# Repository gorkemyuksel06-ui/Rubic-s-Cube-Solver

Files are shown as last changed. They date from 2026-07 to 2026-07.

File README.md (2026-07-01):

# Rubik Küp Çözücü Robot

Hacettepe Üniversitesi ELE402 bitirme projesi kapsamında geliştirilen otonom Rubik Küp çözücü robot. Sistem şu anda **Telekom Laboratuvarında** hazır kurulu motor sürücüleriyle birlikte takılı halde bulunmaktadır.

## Sistem Detayları
* **Yazılım & Donanım:** Kodların tamamı **Python** dilinde yazılmıştır ve **Raspberry Pi** üzerinde çalışmaktadır. Çalıştırmak için gereken tüm kodlar bu depoya yüklenmiştir.
* **Algoritma ve Tarama:** Küpün çözümü için **Kociemba algoritması** kullanılmaktadır. Tarama işlemi bu algoritmanın kuralına uygun olarak yapılır (Tarama **Yeşil** merkezli yüzden başlar ve belirlenen sırayla devam eder).
* **Mekanik Durum:** Sistemin 3D dosyaları depoya eklenmiştir. Yazılımsal olarak hiçbir sorun bulunmamaktadır; kodlar ve algoritma sorunsuz çalışmaktadır. Ancak **mekanik anlamda geliştirme yapılması gereklidir.** Projeyi devralacak kişilerin daha stabil bir mekanik tasarım üzerine yoğunlaşması tavsiye edilir.

## Arayüz (UI) İşlevleri
Sistemi kontrol etmek için geliştirilen arayüzün temel özellikleri ve işlevleri şunlardır:
* **Tarama Modülü:** Yeşil yüzden başlayarak Kociemba dizilimine göre küpün renk matrisini kameradan alır ve kaydeder.
* **Çözüm (Algoritma) Motoru:** Taranan güncel renk durumunu işleyerek küpü çözecek minimum hamle dizisini hesaplar.
* **Hareket (Motor) Kontrolü:** Hesaplanmış olan hamle dizisini, Raspberry Pi pinleri üzerinden doğrudan motor sürücülerine aktararak fiziksel çözümü başlatır.
* **Talimatlar ve Durum Paneli:** Tarama sırası, adım takibi ve sistemin o anki durumuyla ilgili kullanıcıya gerekli bilgileri sağlar.

> **Önemli Not:** Arayüz üzerinde sistemi kullanmak için gerekli tüm talimatlar halihazırda bulunmaktadır. Ancak sistemin veya kod bloklarının tam olarak arka planda ne yaptığını daha iyi anlamak isterseniz, ilgili kodları herhangi bir yapay zekaya atarak her şeyi madde madde ve kolayca öğrenebilirsiniz.

## Geliştiriciler
* Görkem Yüksel
* Özge Erdem

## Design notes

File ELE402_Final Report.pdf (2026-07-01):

# ELE 402 - GRADUATION PROJECT II FINAL REPORT

HACETTEPE UNIVERSITY
DEPARTMENT OF ELECTRICAL AND ELECTRONICS ENGINEERING

PROJECT TITLE: Rubik’s Cube Solver

PROJECT GROUP MEMBERS: Özge ERDEM – Görkem YÜKSEL

PROJECT SUPERVISOR: ASSOC. PROF. DR. BARIŞ YÜKSEKKAYA

SUBMISSION DATE: 14.04.2026

SPRING 2025-2026

## ABSTRACT

This final report presents the design, implementation, and testing of the Rubik's Cube Solver, an autonomous robotic system developed within ELE 401 and ELE 402. The system scans a scrambled 3 x 3 x 3 Rubik's Cube using a camera, classifies sticker colors with an HSV-based OpenCV pipeline, computes a solution with the Kociemba two-phase algorithm, and physically executes the moves using six NEMA 17 stepper motors. During ELE 401, the software foundation and solver logic were created; during ELE 402, the project was completed as an integrated Raspberry Pi 4B-based prototype with a custom graphical user interface, a six-motor mechanical frame, and a custom PCB for A4988 motor driver synchronization and power distribution. After the interim report, the final version added the graphical interface, full scan-solve-execute synchronization, and a Random Mix feature that scrambles the cube, clears the stored cube state and previous solution, and forces a new solve operation when the Solve command is pressed. The final design demonstrates an endto-end autonomous solution pipeline and provides a low-cost educational platform for robotics, computer vision, embedded systems, and motion planning.

## CONTENTS

## LIST OF FIGURES AND TABLES

Figure 1. Final electromechanical architecture of the Rubik's Cube Solver | 5
Figure 2. Camera-based color acquisition pipeline | 9
Figure 3. Mechanical system and final six-motor prototype | 10
Figure 4. Preliminary system architecture from the interim design | 12

Figure 5. Custom graphical user interface used for live state display and manual correction
| 13
Figure 6. OpenCV color detection and ROI mapping on the Raspberry Pi | 14

Figure 7. Custom PCB layout and transition from breadboard wiring to centralized motor
control | 16
Figure 8. Final state flowchart with Random Mix and state reset behavior | 18
Figure 9. Standard Rubik's Cube move notation used by the solver and motor parser | 19
Table 1. Main final design requirements and constraints | 5
Table 2. Random Mix feature behavior and validation points | 11
Table 3. Estimated cost analysis of the final prototype | 20

## 1. INTRODUCTION

The Rubik's Cube Solver project aims to build an autonomous robotic system that can solve a standard 3 x 3 x 3 Rubik's Cube without manual intervention after the cube is placed into the mechanism. The final system combines computer vision, embedded control, motor driver electronics, mechanical design, and a graphical user interface. The overall goal is to convert a visually observed scrambled cube into a valid cube-state string, generate a move sequence using the Kociemba two-phase algorithm, and physically rotate the cube faces with six independent stepper motors.

In ELE 401, the project mainly focused on the software concept: the cube-state representation, initial color detection trials, solver integration, and a mobile-applicationoriented workflow. In ELE 402, the project moved from a conceptual and software-only state into an integrated physical prototype. The architecture was redesigned around a Raspberry Pi 4B so that image acquisition, OpenCV processing, solving, GUI control, and motor commands could run locally on a single embedded platform.

The interim report documented two major design iterations: the first iteration established the Raspberry Pi software pipeline with OpenCV and Kociemba, while the second iteration focused on the custom PCB, stepper motor actuation, and 3D-printed mechanical frame. In the final period, the system was further improved with a functional GUI, synchronized scansolve-execute operation, and a Random Mix feature. In this feature, the robot randomly scrambles the cube, intentionally clears the saved cube state and previous solution, and waits for a new Solve command. Therefore, the system does not simply reverse the random sequence; it scans and solves the newly mixed cube again. This final report presents the complete project description, standards, constraints, methods, design iterations, final design, cost analysis, teamwork, and conclusions.

## 2. PROJECT DESCRIPTION

The project is a mechatronic Rubik's Cube solving robot. The user places a cube inside the mechanical frame and starts the operation from the GUI. The camera captures cube-face images, and the software detects the sticker colors using HSV-based segmentation. The detected colors are displayed in the GUI so that the user can manually correct possible detection errors before solving. After a valid cube state is obtained, the Kociemba solver generates a sequence of moves such as U, R', F2, B, L', or D2. The motor-control layer parses these moves and sends step and direction signals to A4988 drivers, which control six NEMA 17 stepper motors, one motor for each cube face.

The final prototype uses a Raspberry Pi 4B as the central controller. It coordinates the camera, OpenCV scripts, GUI, solver, GPIO outputs, motor drivers, and state memory. The custom PCB reduces wiring complexity by centralizing A4988 driver connections, Raspberry Pi GPIO connections, power distribution, and common ground routing. The 3D-printed frame holds the cube in a fixed position and aligns the six motors with the six cube faces. This architecture supports automatic solving, GUI-based manual verification, and the newly added Random Mix command.

Table 1. Main final design requirements and constraints

Requirement / Constraint | Final implementation
Autonomous cube solving | The system performs scan, GUI verification, Kociemba solving, move parsing, and motor execution on the Raspberry Pi.
Six-face actuation | Six NEMA 17 motors are driven through A4988 drivers; one motor is assigned to each cube face.
Solution efficiency | The solver uses the Kociemba two-phase algorithm, targeting solutions under 20 moves for the final demonstration.
Real-time user visibility | The GUI displays the live cube state and allows manual correction before solving.
Random Mix validation | Random Mix scrambles the cube with motor commands, clears stored state, and requires a new solve operation.
Low-cost prototype | The design relies on accessible components: Raspberry Pi, A4988 drivers, NEMA 17 motors, 3D-printed parts, and a custom PCB.

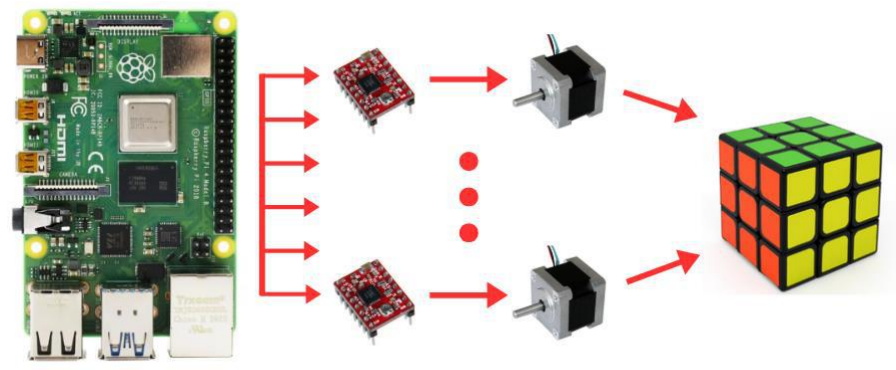
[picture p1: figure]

Figure 1. Final electromechanical architecture of the Rubik's Cube Solver

## 3. ENGINEERING STANDARDS AND DESIGN CONSTRAINTS

## 3.1. ENGINEERING STANDARDS

The final design is a university prototype and is not claimed to be formally certified. However, the design process follows relevant engineering standards and good-practice principles in software, electronics, and mechatronic implementation.

IPC-2221, Generic Standard on Printed Board Design, is relevant to the custom PCB because the board includes motor driver modules, power-distribution paths, connector placement, and signal routing between the Raspberry Pi and six A4988 drivers. In accordance with this design logic, high-current motor paths were separated from low-current GPIO signals as much as possible, connectors were organized to reduce wiring errors, and the PCB was used to improve reliability compared with the breadboard prototype.

IEC 62368-1 safety principles are relevant because the prototype combines a low-voltage computing unit, external motor power, and moving mechanical parts. Although formal product certification was outside the scope of the graduation project, the final design separates logic-level control from motor power, uses a common ground reference, avoids exposed high-voltage circuitry, and keeps the moving cube mechanism inside a fixed frame during operation.

ISO/IEC/IEEE 12207 software life-cycle principles are also applicable at the project level. The final software was divided into color acquisition, GUI verification, solver, random-mix generation, state-memory management, move parsing, and motor-control modules. This modular structure made debugging and final integration easier.

## 3.2. DESIGN CONSTRAINTS

The project was constrained by budget, component availability, time, mechanical precision, lighting conditions, and embedded computation. The robot had to be realizable with parts that could be obtained and assembled within the ELE 402 schedule. The six-motor frame had to fit a standard 3 x 3 x 3 cube while leaving enough clearance for face rotations. The stepper motors had to rotate cube faces by 90 degrees and 180 degrees with sufficiently low angular error. On the software side, the color detection method had to be fast enough to run on the Raspberry Pi and robust enough for the GUI to create a valid cube-state string. The final GUI correction step was therefore included as a practical constraint-management method: a wrong color can be corrected before the solver is run.

## 4. SUSTAINABLE DEVELOPMENT GOALS

The project supports several Sustainable Development Goals at the prototype and educational level. Goal 4, Quality Education, is the strongest match because the robot is a hands-on learning platform for computer vision, embedded systems, motor control, printedcircuit-board design, and mechanical integration. Students can observe how a real mechatronic system moves from algorithmic planning to physical actuation.

Goal 9, Industry, Innovation and Infrastructure, is also supported because the project integrates a custom PCB, a multi-motor actuation structure, and an embedded perceptionand-control pipeline. The architecture is directly related to broader automation tasks such as pick-and-place systems, sorting mechanisms, and low-cost robotic testbeds. Goal 12, Responsible Consumption and Production, is addressed by using 3D-printed replaceable parts and a modular PCB-based architecture, which makes maintenance and component replacement easier than rebuilding the whole system.

## 5. LITERATURE REVIEW

A Rubik's Cube state can be described by the colors or cubie positions of its 54 stickers. Standard cube notation defines face moves U, D, F, B, R, and L, along with prime moves for counter-clockwise rotation and the suffix 2 for 180-degree rotation. This notation is suitable both for solver output and for motor-command parsing because each symbolic move can be mapped directly to one motor, one direction, and one angle.

The selected solving method is the Kociemba two-phase algorithm. Compared with a bruteforce search, Kociemba's approach reduces the solution search space by dividing the problem into phases and using precomputed move tables. This makes it practical to run the solver on an embedded platform such as a Raspberry Pi. The final project therefore uses Kociemba output as the bridge between visual cube-state recognition and physical motor control [1], [2].

For perception, OpenCV is used because it provides efficient image acquisition, color-space conversion, filtering, and region-of-interest operations. HSV color representation was preferred over direct RGB comparison because hue, saturation, and value provide a more intuitive separation of sticker colors under moderate lighting variation. Nevertheless, the interim tests showed that red/orange overlap and reflections can still cause errors, so the final system includes a GUI correction stage before solving [4].

For actuation, stepper motors were selected because they provide discrete angular positioning without requiring a complex feedback controller for a first prototype. A4988 motor driver modules receive step and direction signals from the Raspberry Pi GPIO pins and control the phase currents of the NEMA 17 motors. This structure is simple, widely documented, and suitable for 90-degree and 180-degree cube-face rotations [5], [6].

The literature and project examples on Rubik's Cube solving robots show that successful systems require not only a solver algorithm but also reliable synchronization between scanning, state validation, and mechanical execution. For this reason, the final design emphasizes the full scan-solve-execute loop, GUI verification, and state-reset behavior after random scrambling [7].

## 6. METHODS

## 6.1. CAMERA-BASED COLOR ACQUISITION AND GUI VERIFICATION

The first method is camera-based color acquisition. The camera captures images of cube faces, and each face is divided into nine fixed regions of interest. The mean HSV values of these regions are calculated and classified into the six cube colors: white, yellow, red, orange, blue, and green. The GUI then visualizes the detected state. If one or more stickers are misclassified, the user can manually correct them before the solver is called. This approach was selected because it combines automation with practical robustness: the system remains usable even when lighting conditions are not ideal.

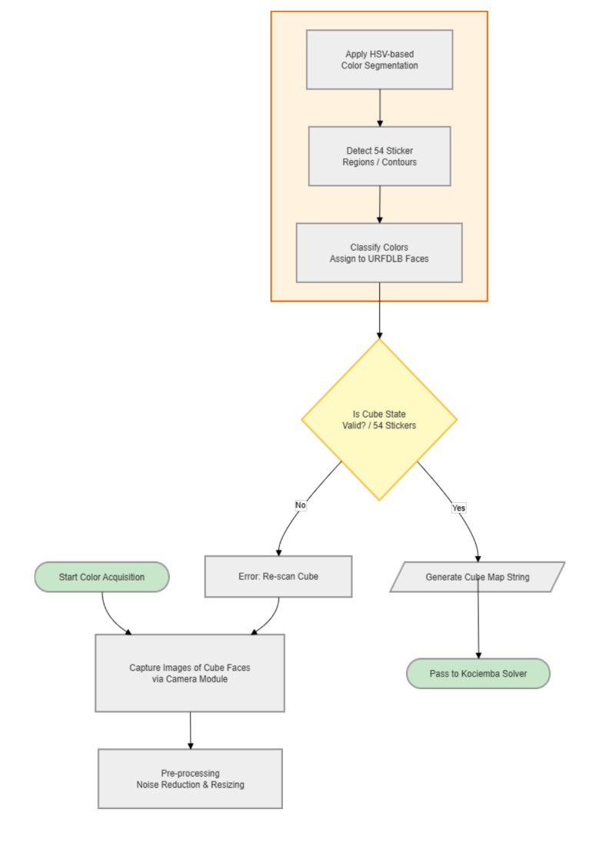
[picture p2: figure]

Figure 2. Camera-based color acquisition pipeline

## 6.2. KOCIEMBA SOLVER AND CUBE STATE ENCODING

The second method is solver-based motion planning. After the GUI confirms that the cube state is valid, the 54 stickers are converted into the face-order required by the solver. The Kociemba module returns a move list in standard notation. The motor parser converts each move into motor index, direction, and number of steps. A move without a suffix corresponds to a 90-degree clockwise rotation; a prime move corresponds to a 90-degree counter-clockwise rotation; a move with the suffix 2 corresponds to a 180-degree rotation.

## 6.3. SIX-MOTOR ACTUATION AND PCB-BASED DRIVER CONTROL

The third method is six-motor face-centered actuation. One NEMA 17 stepper motor is assigned to each cube face. A custom PCB holds or connects the A4988 motor driver modules and distributes power and GPIO signals. The PCB was selected instead of a fully breadboarded system because the final design requires many repeated motor-driver connections. Centralized wiring reduces connection errors and improves demonstration reliability.

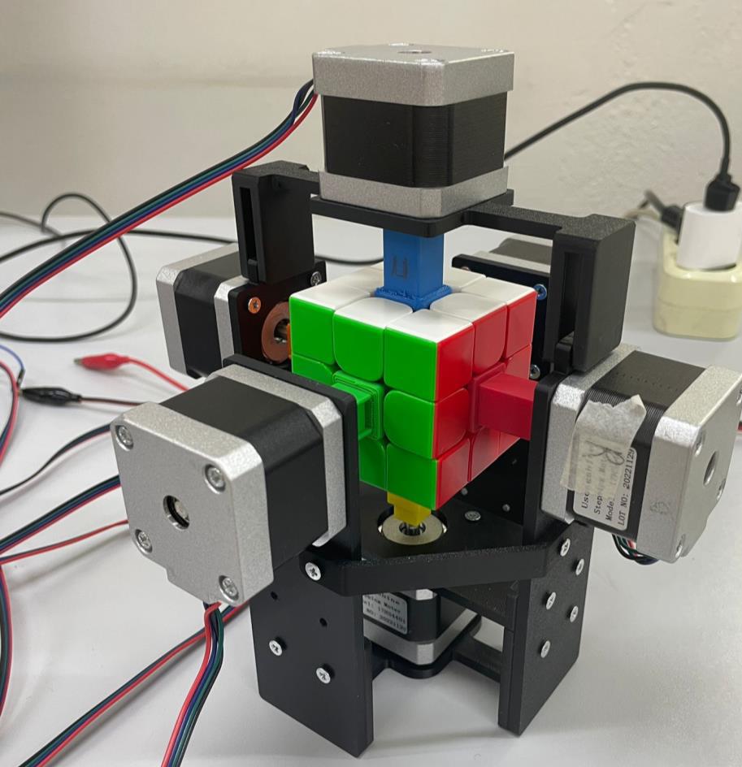
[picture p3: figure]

Figure 3. Mechanical system and final six-motor prototype

## 6.4. RANDOM MIX AND STATE RESET METHOD

The final method added after the interim report is the Random Mix and state reset method. When the user presses Random Mix, the software generates a random legal sequence of cube moves and physically executes this sequence with the motors. After the sequence is executed, the software clears the stored cube-state string and the previous solution list. Therefore, when the user presses Solve, the program cannot simply apply the inverse of the random scramble. It must capture or verify the current cube state again, run the Kociemba solver again, and generate a new solution. This feature validates the autonomy of the complete system.

Table 2. Random Mix feature behavior and validation points

Random Mix step | Purpose in final design
Generate random move sequence | Creates a new physical scramble without requiring the user to hand-mix the cube.
Execute sequence with motors | Verifies that the motor-control layer can perform arbitrary face rotations.
Clear previous state and solution | Prevents the software from solving by reversing a stored scramble sequence.
Wait for Solve command | Forces a new scan/verification/solve operation on the mixed cube.
Run solver again | Demonstrates end-to-end autonomy of the final design.

## 7. PRELIMINARY DESIGN

The preliminary design from ELE 401 was a software-centered structure that combined mobile-app interaction with Python-based solving. The core idea was to obtain the cube colors, send the cube state to a solver, and present the solution to the user. However, this design had two major limitations for the final project: it relied on a separate application pipeline, and it did not yet include a complete physical actuation system.

The preliminary ELE 402 redesign replaced the mobile-oriented workflow with a Raspberry Pibased standalone workflow. The Raspberry Pi was selected as the central controller because it can run Python, OpenCV, the Kociemba solver, a GUI, and GPIO-based motor-control scripts. The preliminary hardware design consisted of a camera module, a six-motor mechanical frame, A4988 drivers, a custom PCB, and a separate motor power supply. The main design parameters were camera position, ROI size, HSV thresholds, cube-face order, motor step count per 90-degree turn, motor speed delay, driver current limit, power distribution, GUI state representation, and emergency stop behavior.

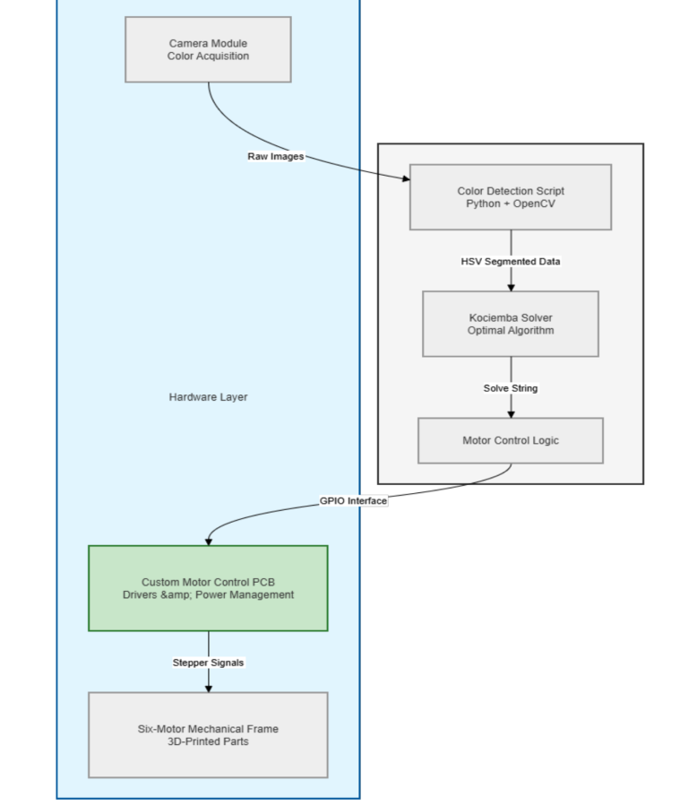
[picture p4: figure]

Figure 4. Preliminary system architecture from the interim design

## 8. PROTOTYPE

The final prototype is a hardware/software integrated Rubik's Cube solving robot. The prototype was built to validate the complete scan-solve-execute sequence in a standalone configuration. Its key features are listed below.

- Raspberry Pi 4B central controller running Python, OpenCV, the GUI, Kociemba solver, random-mix logic, and GPIO motor commands.
- Camera-based color acquisition with HSV segmentation and nine ROIs per cube face.
- Graphical user interface displaying the live cube state and allowing manual color correction before solving.
- Six NEMA 17 stepper motors placed around the cube, one motor per face.
- Six A4988 motor drivers coordinated through Raspberry Pi GPIO pins and a custom PCB.
- 3D-printed frame and cube-face adapters that hold the cube and transfer motor motion to the faces.
- Random Mix feature that scrambles the cube, clears stored state, and requires a fresh solve operation.

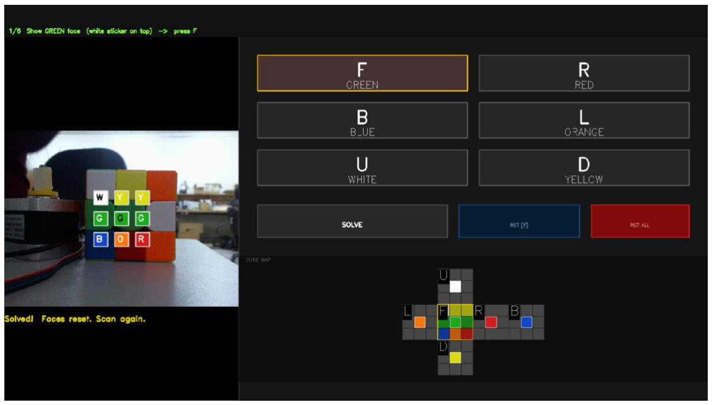
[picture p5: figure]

Figure 5. Custom graphical user interface used for live state display and manual correction

## 9. DESIGN PROCESS AND PROGRESS

The design process was iterative. Each iteration improved a different weakness of the previous version. The first iteration validated the software pipeline, the second iteration added physical motor-control and mechanical implementation, and the third iteration completed the final user workflow with GUI integration, Random Mix, and state-reset logic.

## 9.1. ITERATION 1: SOFTWARE PIPELINE AND COLOR DETECTION

The first iteration focused on developing a self-contained software pipeline on the Raspberry Pi. The camera captured cube-face images, OpenCV converted the images into HSV color space, fixed ROIs isolated the stickers, and the mean HSV values were mapped to six cube colors. The 54 detected stickers were assembled into the solver input string. At this stage, the execution phase remained theoretical and was displayed in the terminal.

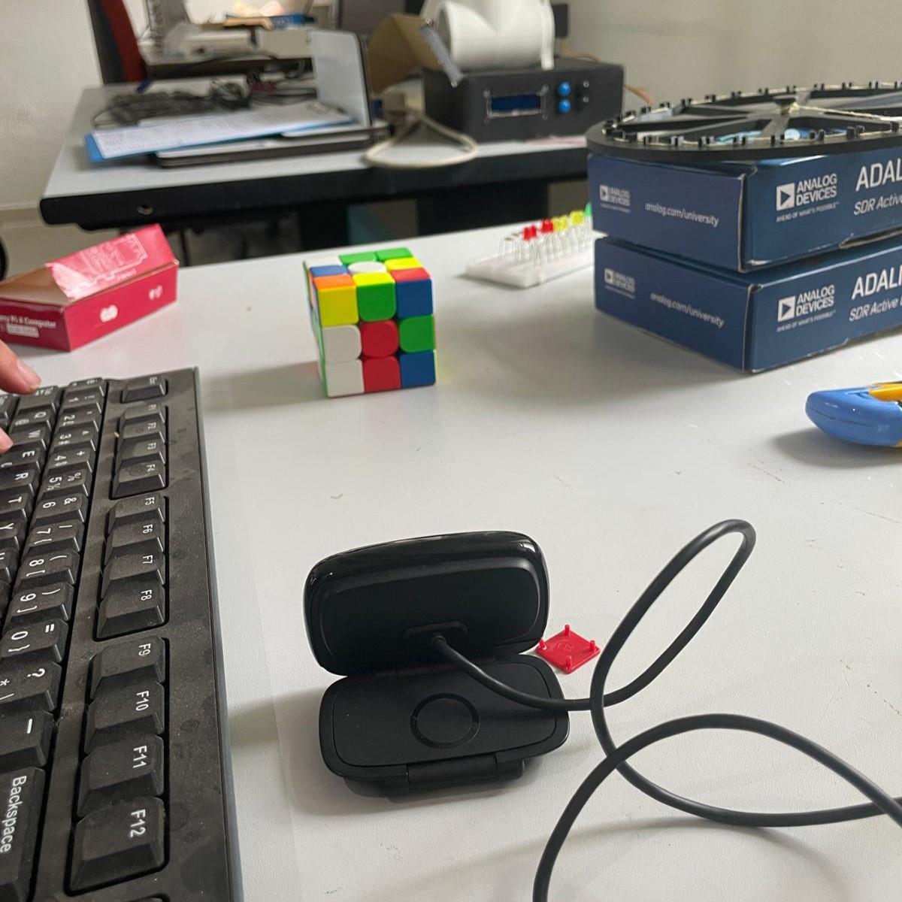
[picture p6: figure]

Figure 6. OpenCV color detection and ROI mapping on the Raspberry Pi

9.1.1. TESTING AND RESULTS
The color-detection module was tested under ambient indoor lighting and direct desk-lamp illumination. In the interim tests, ambient indoor lighting produced approximately 52 correct stickers out of 54 on average, corresponding to about 96 percent accuracy. Under direct desk-lamp illumination, the accuracy decreased to about 89 percent because reflections shifted the apparent hue values. The solver was separately tested with valid cube-state strings and produced valid solutions with an average computation time under 0.8 seconds on the Raspberry Pi.
9.1.2. EVALUATION
This iteration validated the software foundation but revealed two main problems. First, fixed HSV thresholds were sensitive to lighting changes, especially in the red/orange boundary region. Second, the system had no physical actuation, so it could not complete the project goal. The next iteration therefore focused on improved threshold tuning, GUI verification, and hardware integration.

## 9.2. ITERATION 2: MECHANICAL FRAME, PCB, AND MOTOR CONTROL

The second iteration focused on the physical realization of the robot. The mechanical frame was designed and 3D printed. The design uses a face-centered mechanism in which six stepper motors rotate the six cube faces. A custom PCB was designed to host or connect the stepper motor driver modules, organize the GPIO interface, and centralize power distribution. Motor-control scripts were implemented in Python so that each solver move could be translated into a step and direction pulse sequence.

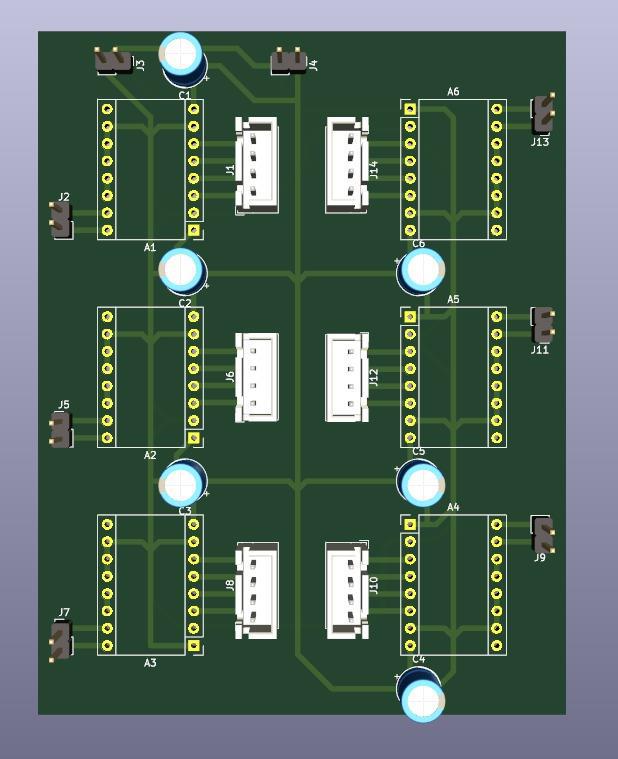
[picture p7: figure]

Figure 7. Custom PCB layout and transition from breadboard wiring to centralized motor control

9.2.1. TESTING AND RESULTS
Before full PCB integration, motor rotation was tested on a breadboard test bench. The interim measurements showed a mean angular error of 1.2 degrees for a 90-degree clockwise turn, 1.5 degrees for a 90-degree counter-clockwise turn, and 2.1 degrees for a 180-degree turn. The 3D-printed parts were also inspected for fit, and the main structural components were found to be suitable for assembly.

9.2.2. EVALUATION
The tests confirmed that the motor-control principle was correct. The remaining weakness was synchronization: the system still needed a final GUI layer, a reliable state transition between scan, solve, and execute, and a method to demonstrate that the robot could solve a cube after it had been automatically mixed by the robot itself. This led to the final iteration.

## 9.3. ITERATION 3: FINAL GUI, RANDOM MIX, AND END-TO-END OPERATION

The third iteration completed the final user workflow. The GUI was integrated with the color-detection, solver, motor-control, and state-memory modules. The user can display the detected cube state, manually correct colors if necessary, solve the cube, execute motor moves, stop the operation, or use the new Random Mix command. Random Mix was added as a final validation feature: the robot first scrambles the cube using a random sequence, then it forgets the stored state and previous solution. When Solve is pressed, the system must solve the current physical cube again.

9.3.1. TESTING AND RESULTS
The final workflow was tested by operating the GUI, executing random motor sequences, clearing the saved state, and running the solve pipeline again. The main observation was that the GUI and state-reset behavior prevented the program from relying on the previous random sequence. This means the solve action remained dependent on the current cube state rather than on a stored inverse scramble. The final poster results reported that the system successfully solves a 3 x 3 x 3 cube using six NEMA 17 stepper motors and a Raspberry Pi 4B, with HSV-based color detection and GUI-supported manual verification.
9.3.2. EVALUATION
The final iteration significantly improved the demonstration value of the project. The Random Mix feature proves that the robot is not only playing back a prepared solution; it can create a new scramble, reset its memory, and solve again from the updated physical configuration. The remaining limitation is that the color detection still depends on lighting stability and user verification. Closed-loop motor feedback and adaptive lighting calibration are recommended for future versions.

## 10. FINAL DESIGN

The final design is a Raspberry Pi 4B-based autonomous Rubik's Cube solving robot. The data path starts from the camera image and ends with physical face rotations. The camera captures cube-face images; OpenCV extracts sticker colors; the GUI displays and validates the state; the Kociemba solver computes the move list; the move parser converts moves into motor commands; the custom PCB and A4988 drivers distribute the control signals; and six NEMA 17 motors rotate the corresponding cube faces.

The final software modules are: image acquisition, HSV segmentation, ROI mapping, GUI display, manual color correction, cube-state validation, Kociemba solving, Random Mix generation, state-memory reset, move parsing, GPIO pulse generation, and stop/error handling. The final hardware modules are: Raspberry Pi 4B, camera, custom PCB, six A4988 drivers, six NEMA 17 motors, power distribution, 3D-printed frame, cube adapters, connectors, and wiring.

The Random Mix command is a central final-design feature. The command generates a random legal move sequence, executes it with the motors, clears the old cube state and solution, and returns the GUI to a ready state. The next Solve command performs a new solve cycle. This design choice makes the demonstration more convincing because the system cannot solve by remembering the random scramble sequence.

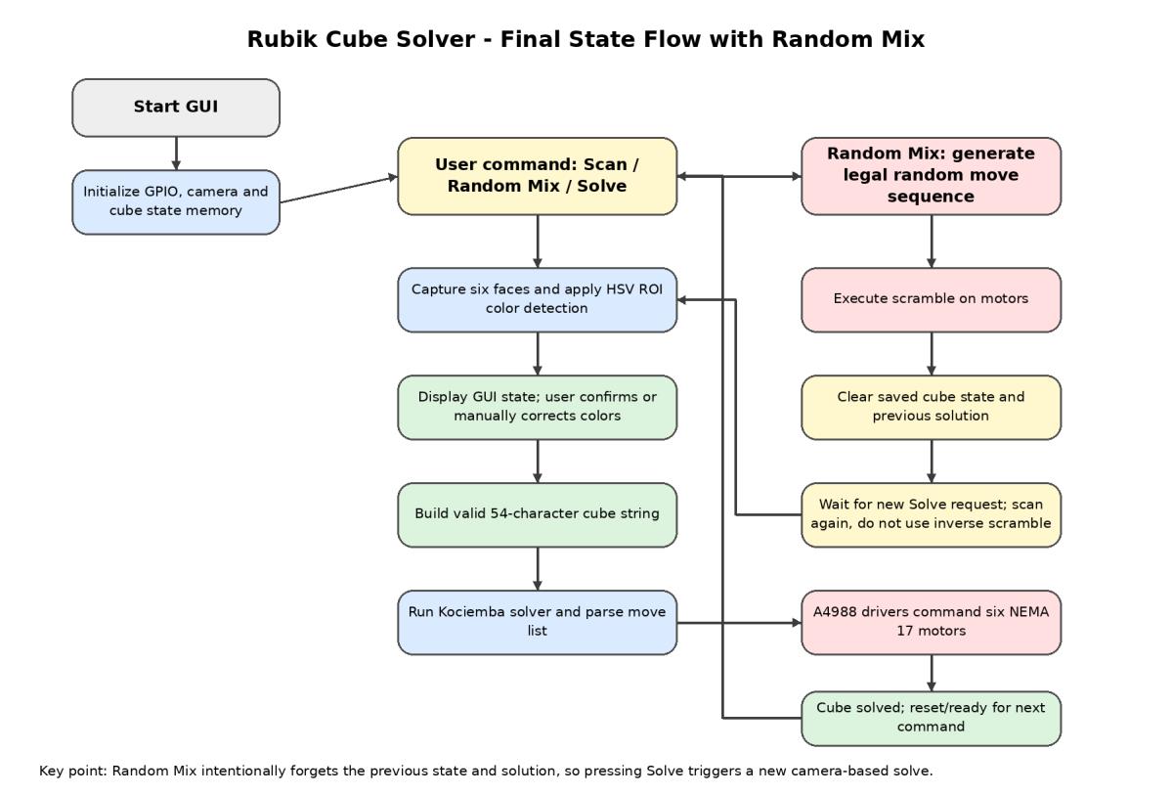
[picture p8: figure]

Figure 8. Final state flowchart with Random Mix and state reset behavior

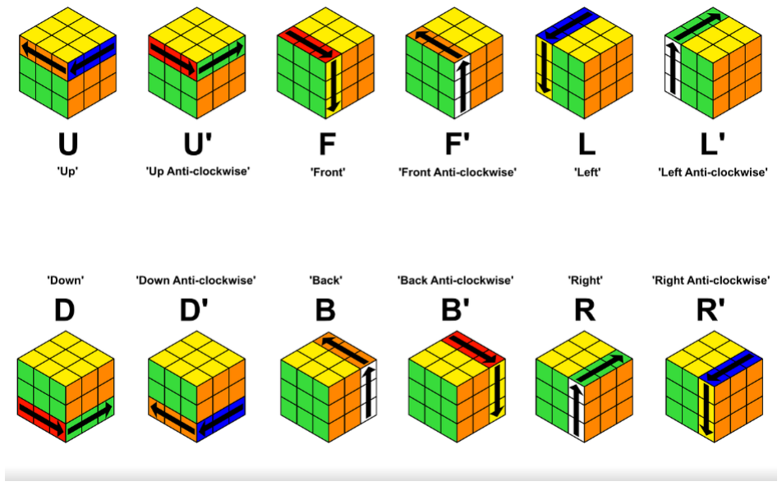
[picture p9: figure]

Figure 9. Standard Rubik's Cube move notation used by the solver and motor parser

The final design meets the core project objectives. It integrates computer vision, motion planning, embedded control, motor driver electronics, and a mechanical frame. Its strongest features are modularity, low-cost implementation, and the GUI-supported correction workflow. Its main weaknesses are sensitivity to lighting conditions, open-loop stepper operation, and the need for careful mechanical alignment. These weaknesses are acceptable for a graduation-project prototype and provide clear directions for future improvement.

## 10.1. MEETING THE CONSTRAINTS AND ENGINEERING STANDARDS

The final design meets the functional constraint of scan-solve-execute operation by using the Raspberry Pi as a single coordination unit. It meets the mechanical constraint through a six-motor frame that allows each cube face to be rotated independently. It meets the cost constraint by relying on affordable and accessible components rather than industrial robot hardware. The PCB improves reliability and follows the PCB-design intent of IPC-2221 by replacing unstable breadboard wiring with organized routing and connectors. Low-voltage safety principles were addressed by separating logic and motor power, limiting the prototype to low-voltage operation, securing the cube in a frame, and avoiding user contact with moving parts during operation.

The software was organized into modules in line with software life-cycle good practice. Color acquisition, GUI verification, solver logic, random mixing, state reset, and motor-control functions can be tested separately. The final Random Mix behavior also satisfies a validation constraint: solving must be based on the actual cube state after scrambling rather than on a stored solution.

## 10.2. COST ANALYSIS

The cost analysis below gives estimated prototype costs. Actual prices may vary depending on supplier, exchange rate, and previously available lab materials.

Table 3. Estimated cost analysis of the final prototype

Component | Quantity | Estimated unit cost (USD) | Estimated subtotal (USD)
Raspberry Pi 4B | 1 | 85 | 85
Camera / webcam module | 1 | 15 | 15
NEMA 17 stepper motor | 6 | 12 | 72
A4988 stepper motor driver | 6 | 3 | 18
Custom PCB manufacturing | 1 | 25 | 25
12 V motor power supply | 1 | 20 | 20
3D-printed PLA frame and adapters | 1 set | 30 | 30
Connectors, wiring, screws, couplers | 1 set | 30 | 30
Rubik's Cube | 1 | 8 | 8
Total estimated cost | | | 303

The estimated total cost is approximately 303 USD. Considering that the prototype includes computer vision, a graphical interface, six independent motors, motor drivers, a custom PCB, and a mechanical frame, the cost is reasonable for an educational mechatronics platform.

## 11. TEAMWORK

The project was completed by Özge Erdem and Görkem Yüksel. Both members contributed to the overall system design, debugging, testing, and final demonstration. The individual contributions are summarized below.

- Özge Erdem (2210357057): Worked on the computer-vision pipeline, HSV color calibration, GUI workflow, manual correction logic, Random Mix state-reset behavior, system testing, report preparation, and final documentation.
- Görkem Yüksel (2210357094): Worked on mechanical design, 3D-printed frame preparation, PCB design and motor-driver organization, stepper motor control tests, system integration, poster preparation, and final demonstration support.
- Joint work: Kociemba solver integration, cube-state validation, move parser debugging, end-to-end testing, final result evaluation, and preparation of presentation materials.

## 12. COMMENTS AND CONCLUSIONS

This report presented the final status of the Rubik's Cube Solver graduation project. The project started as a software-oriented solver concept and was completed as a functional mechatronic prototype. The final design uses a Raspberry Pi 4B, camera-based HSV color detection, Kociemba solving, GUI-based manual verification, a custom PCB, six A4988 motor drivers, six NEMA 17 stepper motors, and a 3D-printed mechanical frame. The design achieved the main objective of building an autonomous system that can scan, solve, and physically manipulate a standard 3 x 3 x 3 Rubik's Cube.

The most important final improvement was the Random Mix feature. With this feature, the robot can scramble the cube by itself, clear the stored cube state and previous solution, and then solve the cube again when the Solve command is pressed. This addition strengthens the demonstration because it verifies that the system relies on the current physical cube state rather than a memorized inverse scramble.

The final design is successful as a low-cost educational prototype. It demonstrates the integration of computer vision, embedded programming, motor control, PCB design, and mechanical prototyping. The remaining limitations are mostly related to lighting sensitivity, open-loop motor control, and mechanical tolerance. Future work should focus on adaptive lighting compensation, automatic camera calibration, closed-loop face-position feedback using encoders or limit sensors, improved acceleration/deceleration profiles, and a more rigid enclosure for repeatable alignment.

## REFERENCES

[1] H. Kociemba, "Two-phase algorithm for solving Rubik's Cube," Cube Explorer Documentation, 1997. Available: https://kociemba.org/cube.htm
[2] H. Kociemba, "hkociemba/RubiksCube-TwophaseSolver," GitHub, Jan. 08, 2021. Available: https://github.com/hkociemba/RubiksCube-TwophaseSolver
[3] D. Singmaster, Notes on Rubik's Cube. Enslow Publishers, 1981.
[4] G. Bradski, "The OpenCV Library," Dr. Dobb's Journal of Software Tools, 2000.
[5] Raspberry Pi Foundation, "Raspberry Pi Documentation - Hardware and GPIO," 2024. Available: https://www.raspberrypi.com/documentation/
[6] Allegro MicroSystems, "A4988 DMOS Microstepping Driver with Translator and Overcurrent Protection," Datasheet.
[7] C. T. Huang et al., "Design and control of a Rubik's Cube solving robot," IEEE Transactions on Automation Science and Engineering, vol. 14, no. 3, pp. 1385-1395, Jul. 2017.
[8] IPC, IPC-2221: Generic Standard on Printed Board Design.
[9] IEC, IEC 62368-1: Audio/video, information and communication technology equipment -Safety requirements.
[10] ISO/IEC/IEEE, ISO/IEC/IEEE 12207: Systems and software engineering - Software life cycle processes.
[11] Autodesk, "Tinkercad - 3D Design and Electronics Modeling," 2024. Available: https://www.tinkercad.com/
[12] Bambu Lab, "MakerWorld - 3D Model Community and Printing Resources," 2024. Available: https://makerworld.com/

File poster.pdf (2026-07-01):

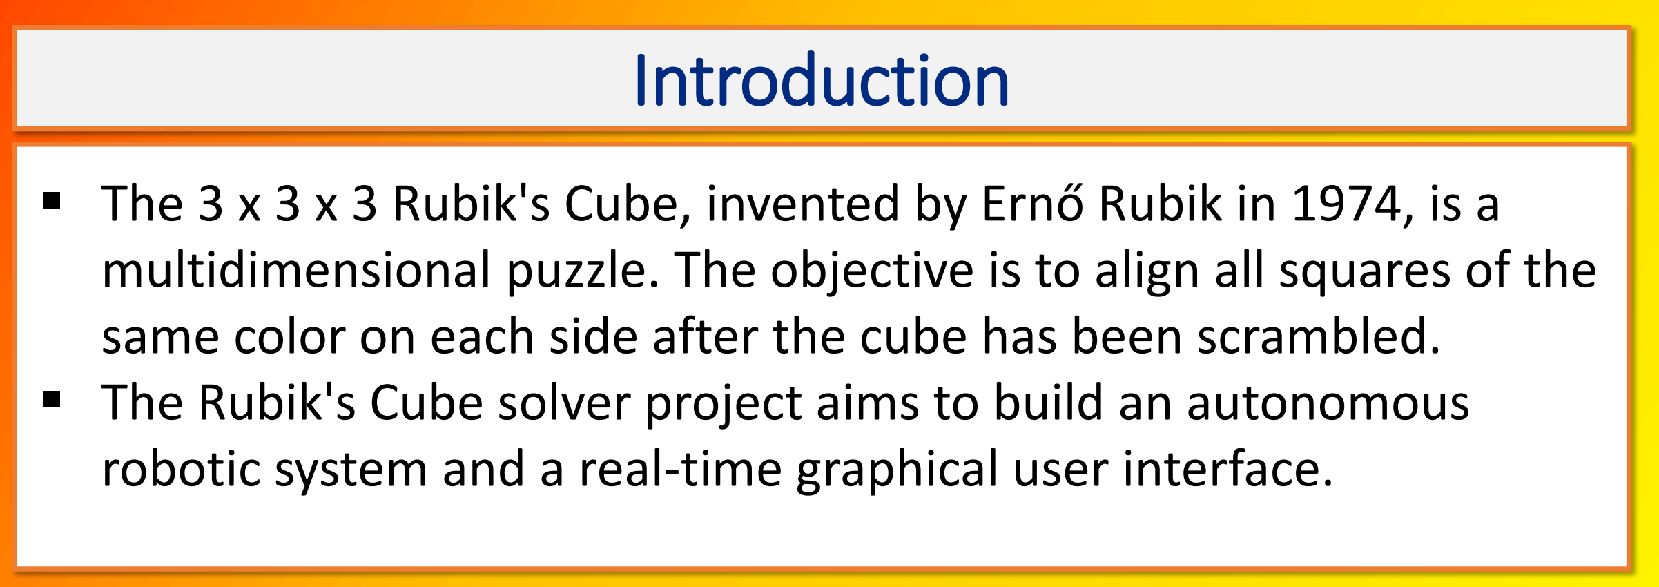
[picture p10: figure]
Introduction

- The 3 x 3 x 3 Rubik's Cube, invented by Ernő Rubik in 1974, is a multidimensional puzzle. The objective is to align all squares of the same color on each side after the cube has been scrambled.
- The Rubik's Cube solver project aims to build an autonomous robotic system and a real-time graphical user interface.

## Supervisor

### Associate Professor Dr. Barış Yüksekkaya

Electrical and Electronics Engineering, Hacettepe University

## Görkem Yüksel, Özge Erdem

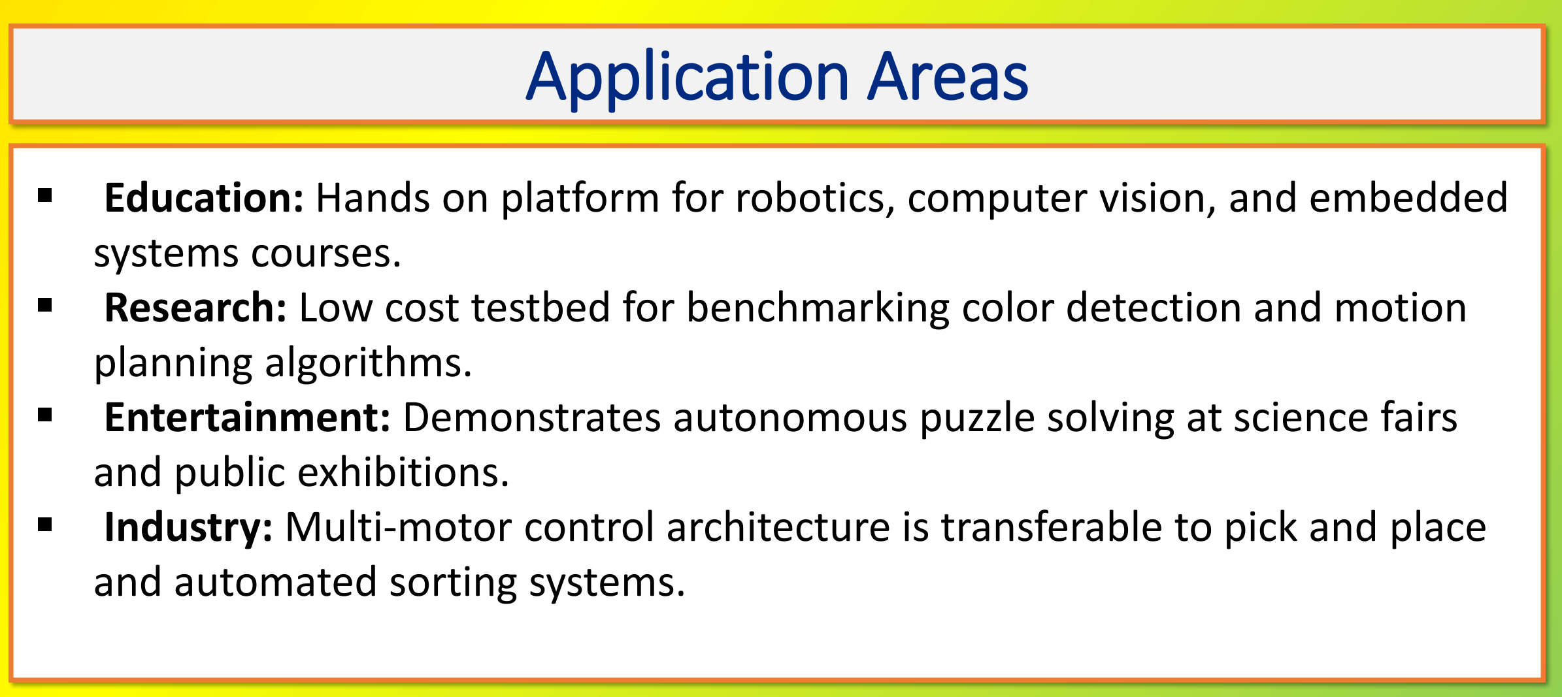
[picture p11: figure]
systems courses.; planning algorithms.; and public exhibitions.; and automated sorting systems.; Application Areas

- Education: Hands on platform for robotics, computer vision, and embedded
- Research: Low cost testbed for benchmarking color detection and motion
- Entertainment: Demonstrates autonomous puzzle solving at science fairs
- Industry: Multi-motor control architecture is transferable to pick and place

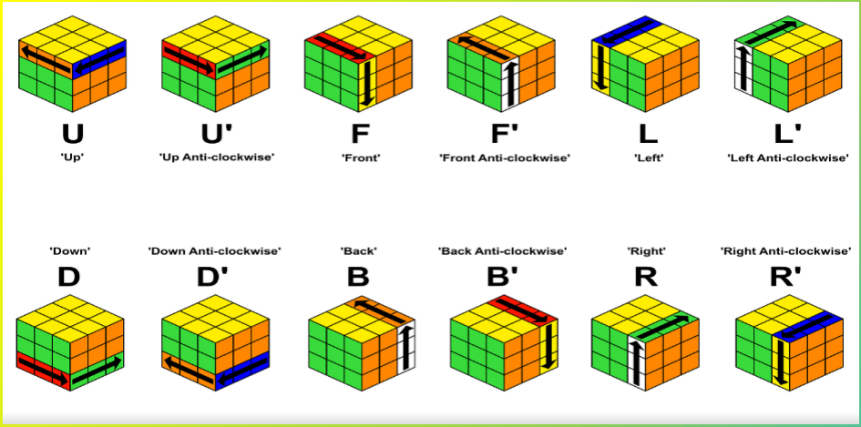
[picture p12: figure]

- Robotic System: A system consisting of 6 independent NEMA 17 stepper motors is built to solve a 3 x 3 x 3 Rubik's Cube
- Performance: The objective is to achieve a solution in less than 20 moves using Kociemba's algorithm.
- Electronics: A custom PCB is utilized to manage motor driver synchronization and power distribution.
- User Interface: A real-time graphical interface is developed to display the live cube state and provide manual correction tools.

## Specifications and Design Requirements

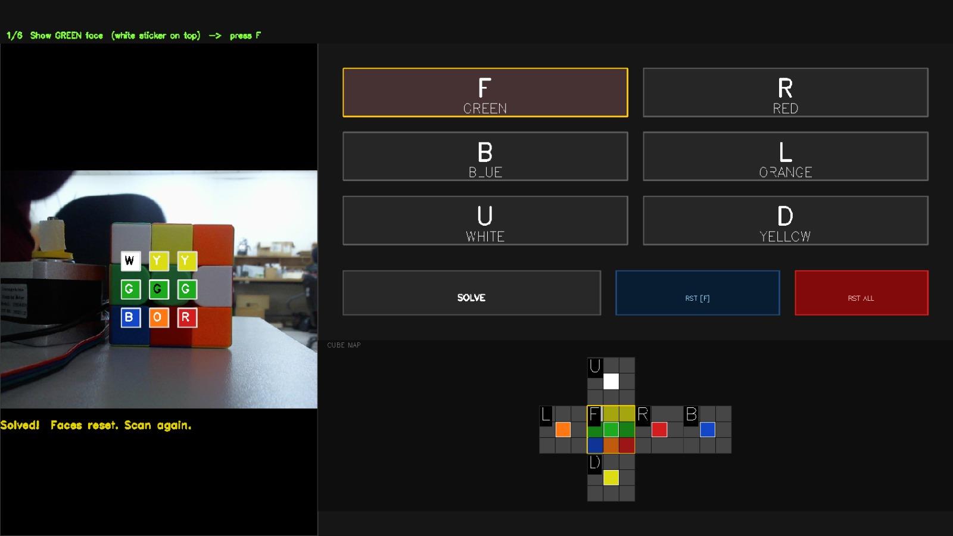
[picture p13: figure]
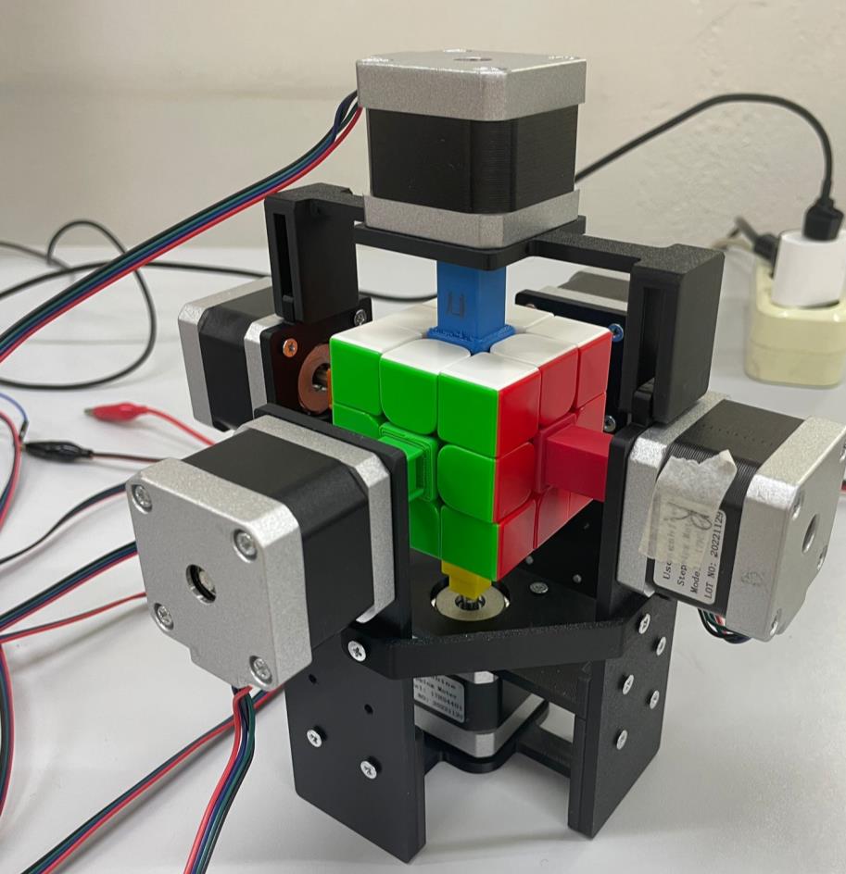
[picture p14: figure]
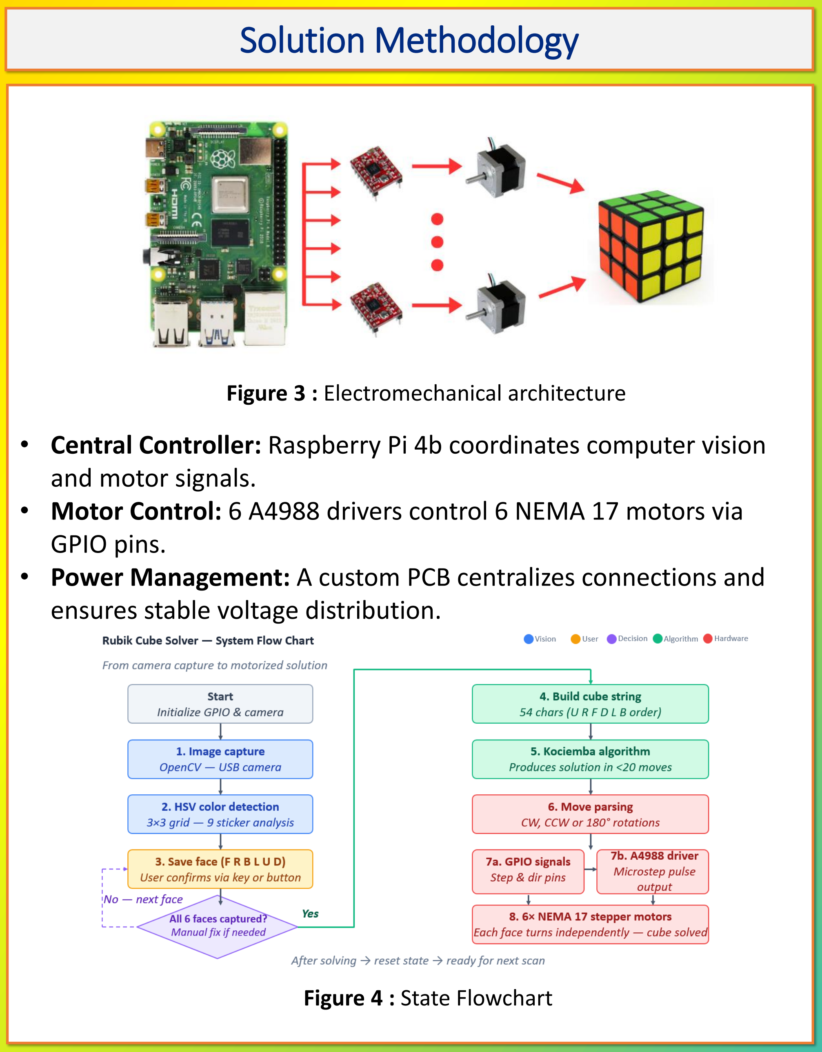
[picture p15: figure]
and motor signals.; GPIO pins.; ensures stable voltage distribution.; Solution Methodology; Figure 4 : State Flowchart

- Central Controller: Raspberry Pi 4b coordinates computer vision
- Motor Control: 6 A4988 drivers control 6 NEMA 17 motors via
- Power Management: A custom PCB centralizes connections and
- Kociemba, H. "hkociemba/RubiksCube-TwophaseSolver," GitHub, Jan. 08,
2021. | https://github.com/hkociemba/RubiksCube-TwophaseSolver
(accessed Nov. 10, 2024).
- Raspberry Pi Foundation, "Raspberry Pi Documentation - Hardware and GPIO," 2024. https://www.raspberrypi.com/documentation/
- "Using Python OpenCV to Detect Squared Regions for Rubik's Cube Scanning,"StackOverflow,2021. https://stackoverflow.com/questions/68559863/using-python-opencv-toaccurately (https://stackoverflow.com/questions/68559863/using-python-opencv-to-accurately-find-squares-from-processed-image-for-rubiks)- (https://stackoverflow.com/questions/68559863/using-python-opencv-to-accurately-find-squares-from-processed-image-for-rubiks)find (https://stackoverflow.com/questions/68559863/using-python-opencv-to-accurately-find-squares-from-processed-image-for-rubiks)- (https://stackoverflow.com/questions/68559863/using-python-opencv-to-accurately-find-squares-from-processed-image-for-rubiks)squares (https://stackoverflow.com/questions/68559863/using-python-opencv-to-accurately-find-squares-from-processed-image-for-rubiks)- (https://stackoverflow.com/questions/68559863/using-python-opencv-to-accurately-find-squares-from-processed-image-for-rubiks)from (https://stackoverflow.com/questions/68559863/using-python-opencv-to-accurately-find-squares-from-processed-image-for-rubiks)- (https://stackoverflow.com/questions/68559863/using-python-opencv-to-accurately-find-squares-from-processed-image-for-rubiks)processed (https://stackoverflow.com/questions/68559863/using-python-opencv-to-accurately-find-squares-from-processed-image-for-rubiks)- (https://stackoverflow.com/questions/68559863/using-python-opencv-to-accurately-find-squares-from-processed-image-for-rubiks)image (https://stackoverflow.com/questions/68559863/using-python-opencv-to-accurately-find-squares-from-processed-image-for-rubiks)- (https://stackoverflow.com/questions/68559863/using-python-opencv-to-accurately-find-squares-from-processed-image-for-rubiks)for (https://stackoverflow.com/questions/68559863/using-python-opencv-to-accurately-find-squares-from-processed-image-for-rubiks)- (https://stackoverflow.com/questions/68559863/using-python-opencv-to-accurately-find-squares-from-processed-image-for-rubiks)rubiks (https://stackoverflow.com/questions/68559863/using-python-opencv-to-accurately-find-squares-from-processed-image-for-rubiks)

## References

- This project was completed within the context of ELE401-402 Graduation Project courses in Hacettepe University, Faculty of Engineering, Department of Electrical and Electronics Engineering.
- We thank Associate Professor Dr. Barış Yüksekkaya for his invaluable contributions to our project.

## Acknowledgements

- Results: The system successfully solves a 3 x 3 x 3 Rubik's Cube autonomously using 6 NEMA 17 stepper motors and a Raspberry Pi 4B. HSVbased color detection identifies all 6 face colors via webcam, supported by a custom GUI for manual verification.
- Performance: The system achieves a high-speed solve, Kociemba's algorithm generates optimal solutions (under 20 moves) in.
- Specifications Achieved: 6-motor high-speed synchronized control via a custom PCB, real-time OpenCV color detection, and a functional graphical interface were successfully implemented.
- Implications: The integration of high speed actuation and real-time computer vision demonstrates an advanced level of system coordination and motion planning.
- Future Work: Adaptive lighting compensation and closed loop feedback could further increase color detection robustness and rotation precision.

## Results and Discussion

Figure 1: Mechanical System Figure 2: Custom Graphical User Interface (GUI)

Figure 3 : Electromechanical architecture

Figure 5: Standard Rubik's Cube move notation

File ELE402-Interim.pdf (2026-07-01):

# ELE 402 - GRADUATION PROJECT II INTERM REPORT

HACETTEPE UNIVERSITY
DEPARTMENT OF ELECTRICAL AND ELECTRONICS ENGINEERING

### PROJECT TITLE: Rubik’s Cube Solver

### PROJECT GROUP MEMBERS: Özge ERDEM – Görkem YÜKSEL

PROJECT SUPERVISOR: ASSOC. PROF. DR. BARIŞ YÜKSEKKAYA

SUBMISSION DATE: 26.04.2026

### SPRING 2025-2026

## TABLE OF CONTENTS

## CONTENTS

TABLE OF CONTENTS | 1
LIST OF FIGURES AND TABLES | 1

### 1. INTRODUCTION | 1

### 2. PROTOTYPE | 2

### 3. DESIGN PROCESS & PROGRESS | 5

### 3.1. ITERATION 1 : SOFTWARE PIPELINE & COLOR DETECTION | 5

### 3.1.1. TESTING AND RESULTS | 7

### 3.1.2. EVALUATION | 7

### 3.2. ITERATION 2 (YOU MAY REPLACE WITH THE NAME OF THE PROCESS) | 8

### 3.2.1. TESTING AND RESULTS | 10

### 3.2.2. EVALUATION | 11

REFERENCES | 13

## LIST OF FIGURES AND TABLES

Figure 1- Overall system architecture of the Rubik’s Cube Solver Robot | 3
Figure 2 - Raspberry pi camera-Based color acquısıtıon pıpelıne | 4
Figure 3 - Real-time OpenCV color detection and region-of-interest (ROI) mapping running on the
Raspberry Pi | 6
Figure 4 - CAD rendering of the mechanıcal frame | 8
Figure 5 - 3D printed mechanical frame components before assembly | 9
Figure 6 - 3D printed central support | 9
Figure 7 - Custom PCB layout desıgn for stepper motors | 10
Figure 8- Design process flowchart | 12

## 1. INTRODUCTION

This report presents the interim progress of the ELE 402 Graduation Project II, a

continuation of the Rubik’s Cube Solver Robot developed in ELE 401. The project aims

to design and build a fully automated system capable of scanning a scrambled Rubik’s

Cube, computing an optimal solution using the Kociemba two-phase algorithm, and

executing the physical moves via a six-motor robotic mechanism.

In the previous semester (ELE 401), the software foundation was established: the

mobile application prototype was created using Flutter, the Kociemba solver was

successfully integrated, and initial color detection experiments were performed. The

physical robot, however, remained at a conceptual design stage.

This semester, the project transitioned into the physical implementation phase. The

primary architectural change from the previous semester is the replacement of the

Flutter+Python mobile pipeline with a Raspberry Pi-based standalone system, where a

camera module handles image acquisition, Python processes color information using

OpenCV, and the Kociemba solver runs locally on the Raspberry Pi. This simplifies the

communication stack and improves system reliability. In addition, the 3D-printed

mechanical parts for the six-motor face-centered rotation mechanism have been

fabricated, and a custom PCB for stepper motor control has been designed and sent to

manufacturing. This report describes the prototype built so far and discusses the two main

design iterations carried out to reach the current state.

## 2. PROTOTYPE

The current prototype of the Rubik’s Cube Solver Robot is a hardware/software integrated

system composed of four main subsystems:

- Raspberry Pi Control Unit: A Raspberry Pi serves as the central processing unit. It runs the color detection script (Python + OpenCV), executes the Kociemba solver, and will issue motor control commands once the mechanical assembly is complete.
- Camera-Based Color Acquisition: A camera module mounted on the Raspberry Pi captures images of each face of the Rubik’s Cube. HSV-based color segmentation is applied to detect and classify the 54 sticker colors.
- Six-Motor Mechanical Frame: The six-motor face-centered rotation mechanism uses one stepper motor per cube face. All 3D-printed structural parts have been fabricated. Assembly is pending integration with the PCB.
- Custom Motor Control PCB: A dedicated PCB has been designed to drive the six stepper motors. The board integrates motor drivers, power management circuitry, and GPIO interfaces for the Raspberry Pi. The board has been submitted for manufacturing.

The purpose of the prototype is to validate the full “scan → solve → execute” pipeline in

an integrated, standalone configuration without reliance on a separate mobile application.

At the current stage, the software pipeline (color detection and solver) is functional on

the Raspberry Pi, the mechanical parts are ready for assembly, and motor rotation logic

has been verified on a test bench.

A placeholder for the system overview figure is provided below. A photograph of the

current physical prototype should be inserted here once the mechanical assembly is

completed.

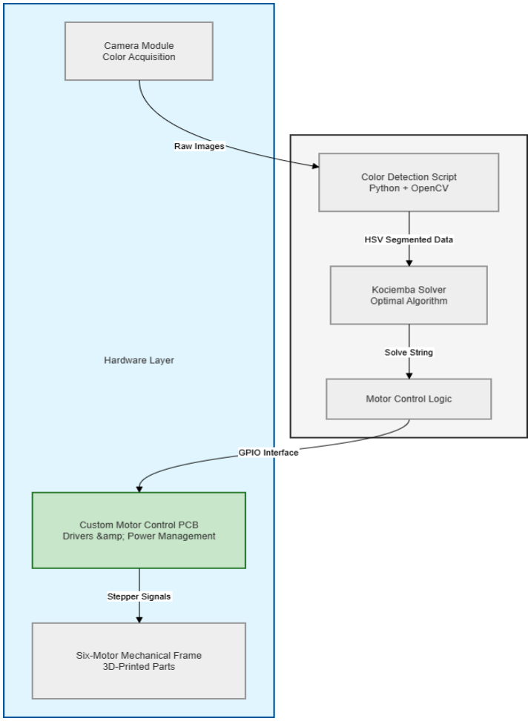
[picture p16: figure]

FIGURE 1- OVERALL SYSTEM ARCHITECTURE OF THE RUBIK’S CUBE SOLVER ROBOT

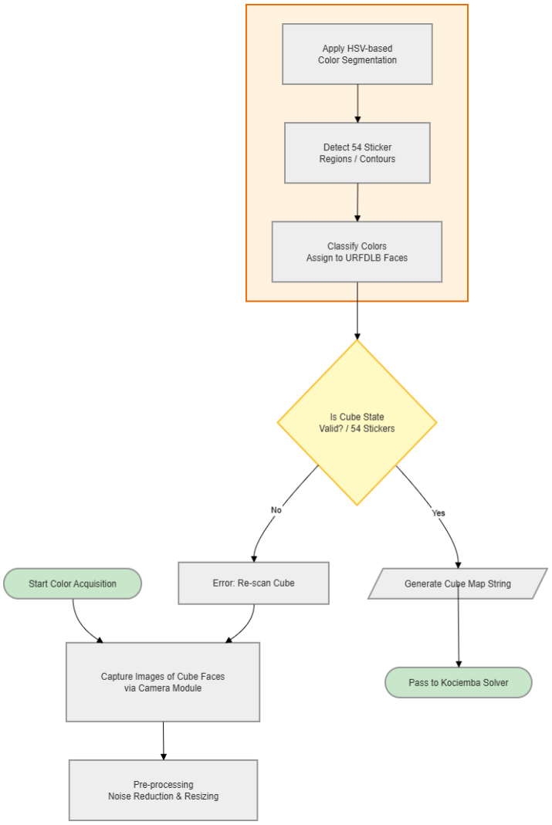
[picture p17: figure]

FIGURE 2 - RASPBERRY PI CAMERA-BASED COLOR ACQUISITION PIPELINE

## 3. DESIGN PROCESS & PROGRESS

The engineering design process for the Rubik’s Cube Solver Robot was carried out in Two main iterations, focusing on the transition from a software-only simulation to a physical hardware prototype.

- First Iteration: This phase was dedicated to developing the core logic on the Raspberry Pi. The primary goal was to establish a functional software pipeline involving OpenCV for color detection and the Kociemba algorithm for solving. At this stage, the system did not include any motor control hardware or physical components. Although the solver worked in a terminal environment, the color detection module suffered from high error rates under varying light conditions, and the "execute" phase of the project remained entirely theoretical.
- Second Iteration: The second iteration focused on the physical implementation and hardware-software integration. A custom motor control PCB was designed and manufactured to interface the Raspberry Pi with six stepper motors. We addressed the previous errors by refining the HSV color segmentation thresholds for improved stability. On the hardware side, all components of the mechanical frame were successfully 3D-printed. While the final assembly of the frame is still in progress, the motor control logic was successfully verified by testing the individual stepper motors. This iteration successfully synchronized the "scan" and "solve" steps with the preliminary "execute" commands, resolving the main synchronization issues from the first phase.

### 3.1. ITERATION 1 : SOFTWARE PIPELINE & COLOR DETECTION

The primary goal of the first design iteration was to establish a functional, selfcontained software pipeline on the Raspberry Pi. This involved achieving reliable color classification for the Rubik’s Cube faces and verifying the Kociemba solving algorithm, operating entirely independent of any physical motor mechanisms or mechanical frame.

The pipeline operates as follows: the Raspberry Pi camera captures an image of each face of the cube. The image is converted from the RGB color space to HSV, and a fixed region-of-interest (ROI) grid is applied to isolate each of the nine sticker regions. The average HSV value within each ROI is computed, and a classifier maps each average value to one of the six cube colors (white, yellow, red, orange, blue, green). The 54 classified colors are assembled into the 54-character state string required by the Kociemba solver. Once a valid state string is obtained, the solver runs locally on the Raspberry Pi and outputs the solution in standard cube notation. At this stage, the execution phase remained theoretical in the terminal environment.

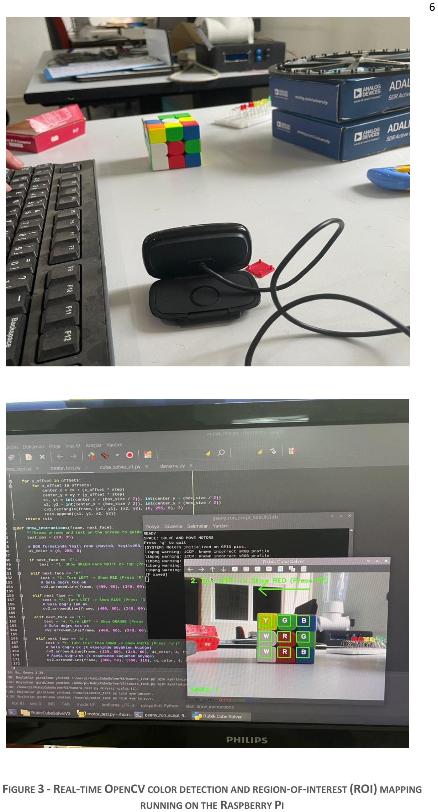
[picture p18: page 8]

FIGURE 3 - REAL-TIME OPENCV COLOR DETECTION AND REGION-OF-INTEREST (ROI) MAPPING RUNNING ON THE RASPBERRY PI

### 3.1.1. TESTING AND RESULTS

The software requirements were tested in two separate modules: color detection accuracy and solver efficiency.

The color detection module was tested by scanning three different scrambled cubes under two lighting conditions: ambient indoor lighting and direct desk lamp illumination. For each configuration, the detected color string was compared against the known ground-truth state.

- Ambient Indoor Lighting: The pipeline achieved correct classification for 52 out of 54 stickers on average, corresponding to an accuracy of approximately 96%. The two misclassified stickers were consistently in the orange/red boundary region, where the HSV hue ranges overlap.
- Direct Desk Lamp Illumination: The accuracy dropped to approximately 89% due to specular reflections on the sticker surfaces, which shifted the apparent hue values.

The Kociemba solver was tested separately with 20 valid, programmatically generated cubestate strings. In all 20 cases, the solver produced a valid solution sequence with an average length of 21 moves and an average computation time of under 0.8 seconds on the Raspberry Pi.

Overall, while the solver performance satisfactorily met the requirements, the color detection robustness under varying lighting conditions was not satisfactorily satisfied.

### 3.1.2. EVALUATION

This initial iteration successfully validated the core logic of the project. The primary strength of the design is the efficiency of the standalone Python implementation on the Raspberry Pi; the Kociemba solver operates rapidly and requires no further optimization.

However, the design exhibited notable weaknesses that must be addressed:

1. Lighting Sensitivity: The use of fixed HSV threshold ranges proved inadequate for changing illumination. The orange/red misclassification is a critical point of failure, as a single wrong color renders the state string invalid.
2. Lack of Physical Actuation: Without hardware integration, the system cannot physically execute the calculated moves, leaving the project incomplete.

To improve the design in the next iteration, the following modifications are necessary:

- Software Enhancement: Refine the HSV color segmentation thresholds or introduce an adaptive calibration step (e.g., sampling the white center sticker first to baseline the lighting) to fix the orange/red overlap.
- Hardware Integration: Transition from a software-only simulation to a physical prototype. This requires designing and manufacturing a custom motor control PCB to interface with the Raspberry Pi, printing the 3D mechanical frame components, and verifying individual stepper motor operations to complete the "scan → solve → execute" pipeline.

### 3.2.ITERATION 2 (YOU MAY REPLACE WITH THE NAME OF THE PROCESS)

The second design iteration focused on the physical realization of the robot. The objectives were: (1) to fabricate the 3D-printed structural components of the six-motor face-centered frame, (2) to design a custom PCB for stepper motor control, and (3) to verify that the motor rotation logic produces correct 90° and 180° face turns.

The mechanical design was finalized in CAD software. The frame consists of six motor mounts, one per cube face, connected by a central support structure that holds the cube in a fixed position during rotation. Stepper motors were chosen for precise angular positioning. The structural components were successfully printed in PLA using the Bambu Lab P1S.

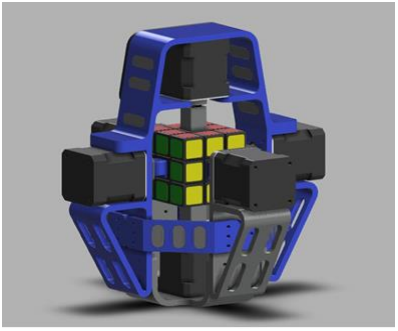
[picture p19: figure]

FIGURE 4 - CAD RENDERING OF THE MECHANICAL FRAME

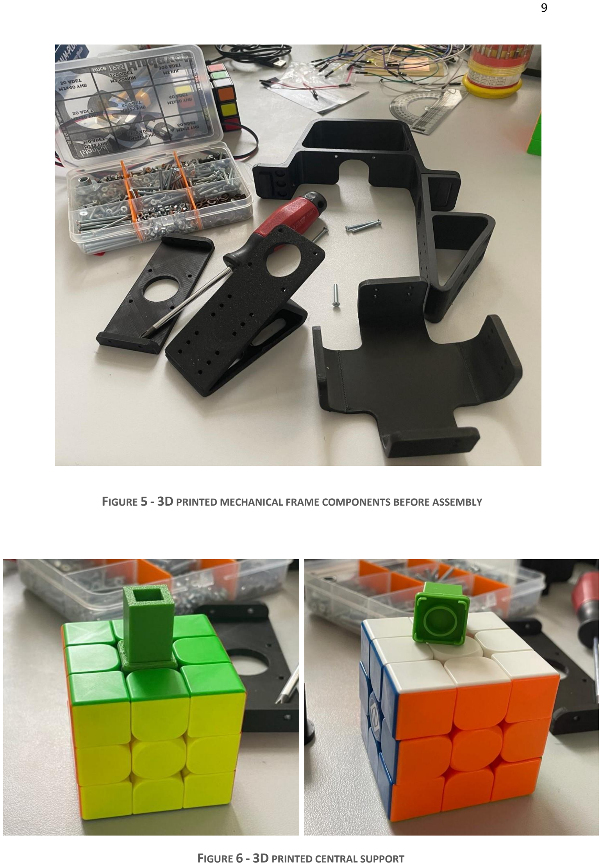
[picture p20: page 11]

FIGURE 5 - 3D PRINTED MECHANICAL FRAME COMPONENTS BEFORE ASSEMBLY

FIGURE 6 - 3D PRINTED CENTRAL SUPPORT

A custom PCB was designed to host six stepper motor driver modules (one per motor), a power regulation circuit, and the GPIO connector interface to the Raspberry Pi. The board was designed to minimize wiring complexity and allow all six motors to be driven simultaneously. The Gerber files were submitted to a PCB manufacturer, and the boards are currently in production.

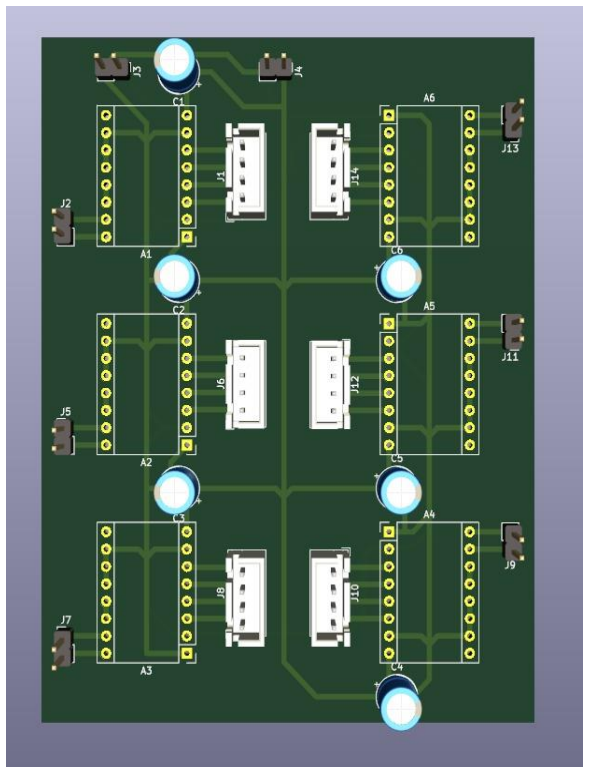
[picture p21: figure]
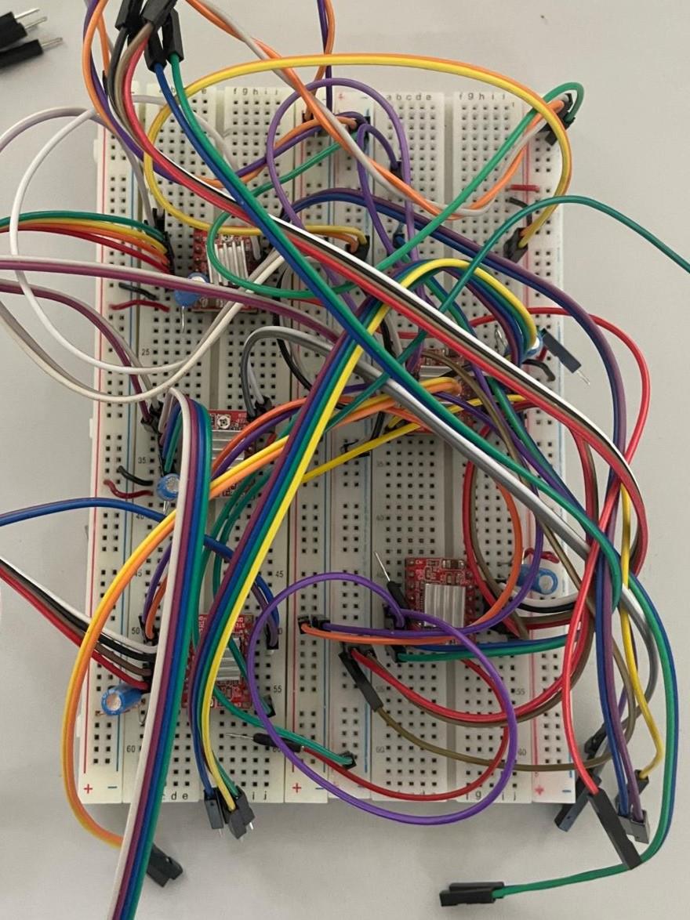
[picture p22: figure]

In the interim, motor control logic was implemented in Python on the Raspberry Pi. Each move in the Kociemba solution sequence (e.g., U, R', F2) is mapped to a GPIO pulse sequence that drives the corresponding stepper motor by 90° or 180°.

### 3.2.1. TESTING AND RESULTS

Motor rotation testing was performed on a breadboard test bench prior to PCB delivery. A single stepper motor was connected to a motor driver module and driven by the Raspberry Pi GPIO. The following tests were conducted:

FIGURE 7 - CUSTOM PCB LAYOUT DESIGN FOR STEPPER MOTORS

- 90° clockwise turn (U move): The motor was commanded to rotate 90° clockwise. The actual rotation was measured using a protractor. The mean angular error across 10 trials was 1.2°, which is within the acceptable tolerance for cube face rotation.
- 90° counter-clockwise turn (U' move): Mean angular error was 1.5° across 10 trials.
- 180° turn (U2 move): Mean angular error was 2.1° across 10 trials. The slightly higher error for 180° turns is attributed to motor inertia and the absence of deceleration profiling in the current implementation.

The 3D-printed structural parts were inspected for dimensional accuracy. All components were within 0.3 mm of the design dimensions. Fit tests confirmed that the motor shaft coupling interfaces align correctly with the cube face adapter plates. However, the full mechanical assembly has not yet been completed, as it is pending delivery of the PCB and final integration.

### 3.2.2. EVALUATION

The motor rotation tests confirm that the stepper motor control logic is functionally correct and that angular accuracy is sufficient for reliable cube face rotation. The mean angular error of approximately 1–2° for 90° turns is acceptable; however, the 2.1° error observed for 180° turns indicates that acceleration and deceleration profiling should be added to the motor control script to reduce inertial overshoot.

The 3D-printed parts show good dimensional accuracy and are ready for assembly. The main bottleneck for completing the physical prototype is the PCB delivery. Once the boards arrive, the following steps will be performed:

- Solder motor driver ICs and passive components onto the PCB.
- Assemble the full six-motor mechanical frame.
- Connect all six motors to the PCB and perform a full end-to-end test.

The main risk at this stage is the PCB delivery timeline. If delays occur, the full integration test may need to be conducted under time pressure. A contingency plan is to revert to the breadboard test bench for the final demonstration if the PCB is not available in time.

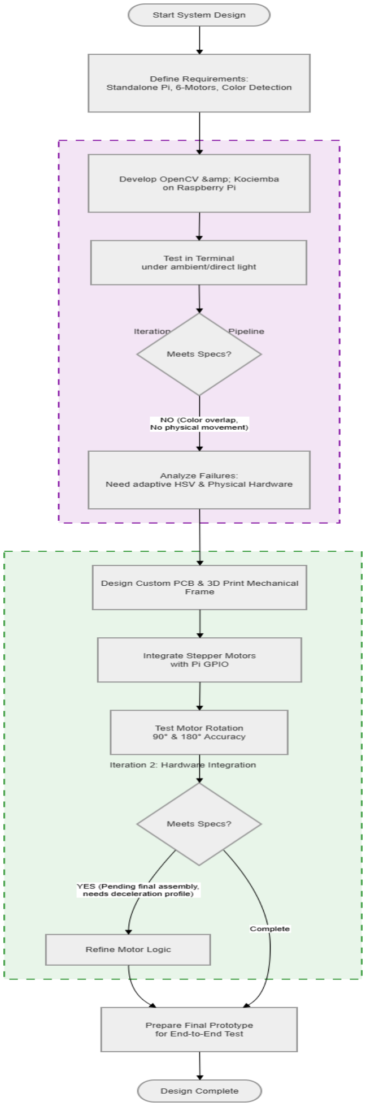
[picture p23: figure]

FIGURE 8- DESIGN PROCESS FLOWCHART

## REFERENCES

### [1] H. Kociemba, "Two-phase algorithm for solving Rubik’s Cube," Cube Explorer Documentation, 1997. Available: https://kociemba.org/cube.htm

[2] D. Singmaster, Notes on Rubik’s Cube. Enslow Publishers, 1981.
[3] G. Bradski, "The OpenCV Library," Dr. Dobb’s Journal of Software Tools, 2000.

### [4] Raspberry Pi Foundation, "Raspberry Pi Documentation - Hardware and GPIO," 2024. Available: https://www.raspberrypi.com/documentation/

### [5] C. T. Huang et al., "Design and control of a Rubik’s Cube solving robot,"

IEEE Trans. Autom. Sci. Eng., vol. 14, no. 3, pp. 1385–1395, Jul. 2017.

### [6] "Using Python OpenCV to Detect Squared Regions for Rubik's Cube Scanning," StackOverflow, 2021. Available: https://stackoverflow.com/questions/68559863/using-python-opencv-to-

accurately-find-squares-from-processed-image-for-rubiks (https://stackoverflow.com/questions/68559863/using-python-opencv-to-accurately-find-squares-from-processed-image-for-rubiks)

[7] Autodesk, "Tinkercad - 3D Design and Electronics Modeling," 2024.

### Available: https://www.tinkercad.com/

### [8] Bambu Lab, "MakerWorld - 3D Model Community and Printing Resources," 2024. Available: https://makerworld.com/

### [9] "Rubik’s Cube Solver 2 – Mechanical & Electronic Build Guide," Instructables, 2021. Available: https://www.instructables.com/Rubiks-Cube-Solver-2/ (https://www.instructables.com/Rubiks-Cube-Solver-2/)

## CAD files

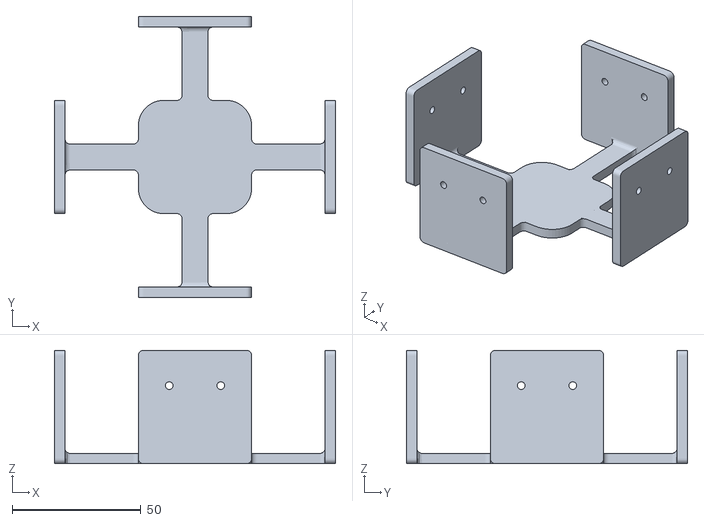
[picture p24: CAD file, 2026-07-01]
Rubic 3D/base web modified final.stl
109.0 x 109.0 x 44.0

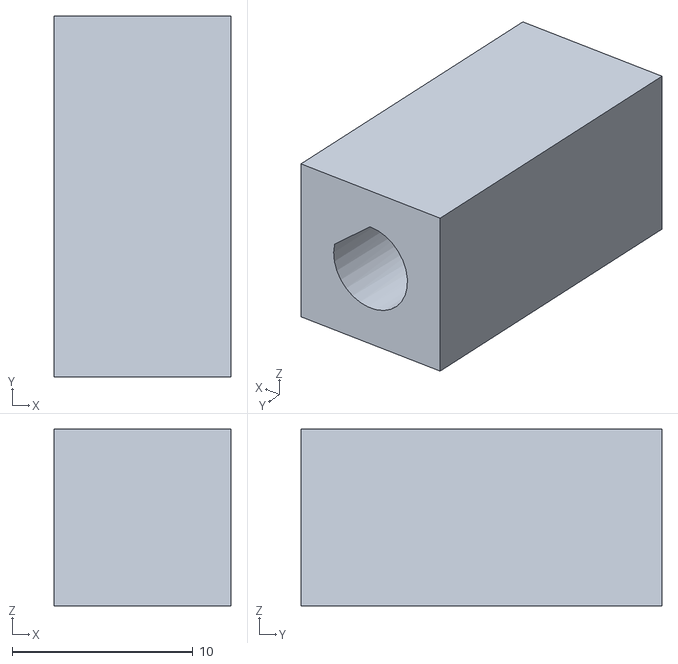
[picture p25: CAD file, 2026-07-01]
Rubic 3D/stepper holder.stl
9.80 x 20.0 x 9.80

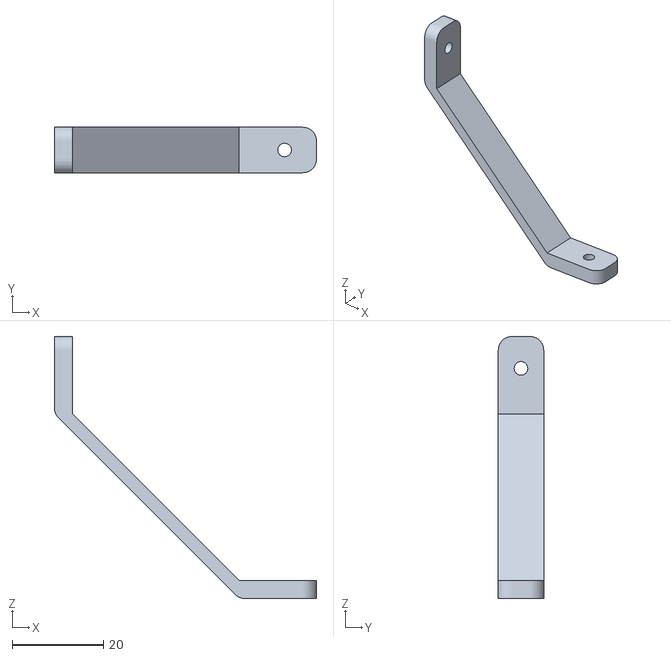
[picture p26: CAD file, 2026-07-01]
Rubic 3D/side support.stl
57.5 x 10.0 x 57.5

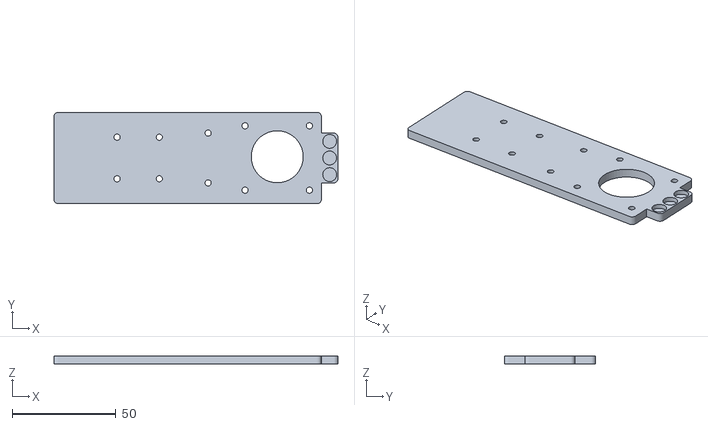
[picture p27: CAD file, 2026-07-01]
Rubic 3D/side plate magnet final.stl
136.7 x 44.0 x 4.00

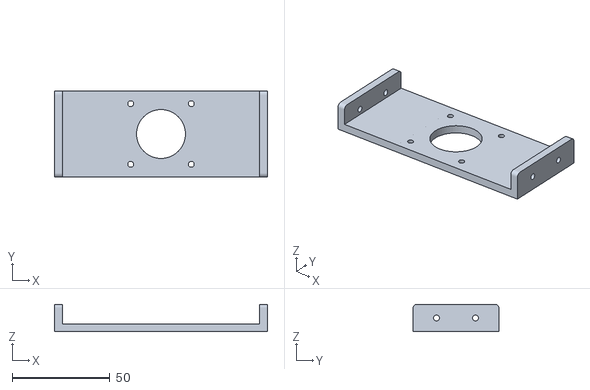
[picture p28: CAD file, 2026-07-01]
Rubic 3D/base plate modified.stl
109.0 x 44.0 x 14.0

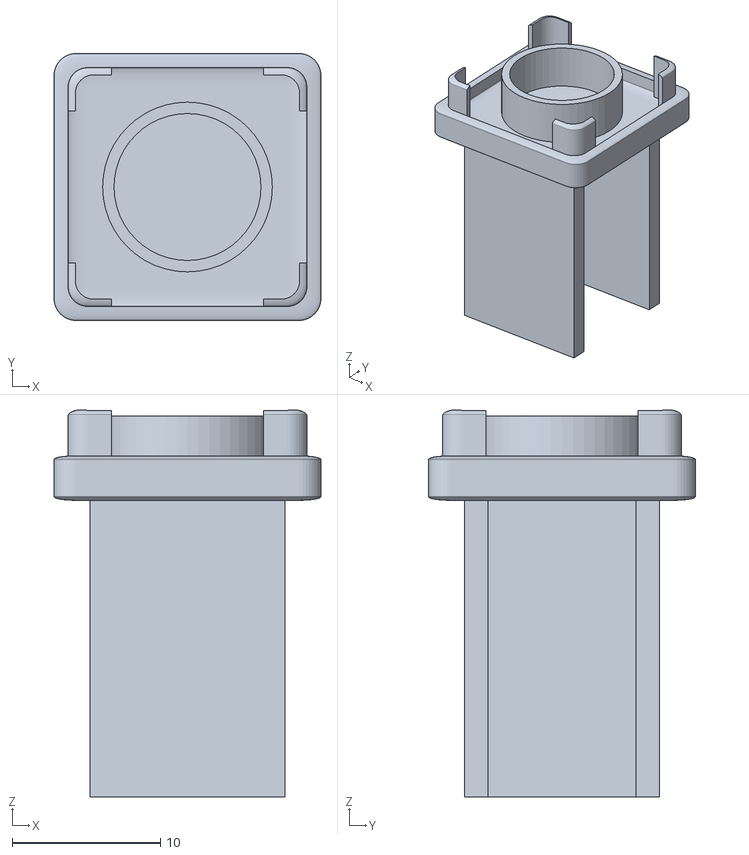
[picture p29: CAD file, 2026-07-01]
Rubic 3D/cube holder piece.stl
18.0 x 18.0 x 26.1

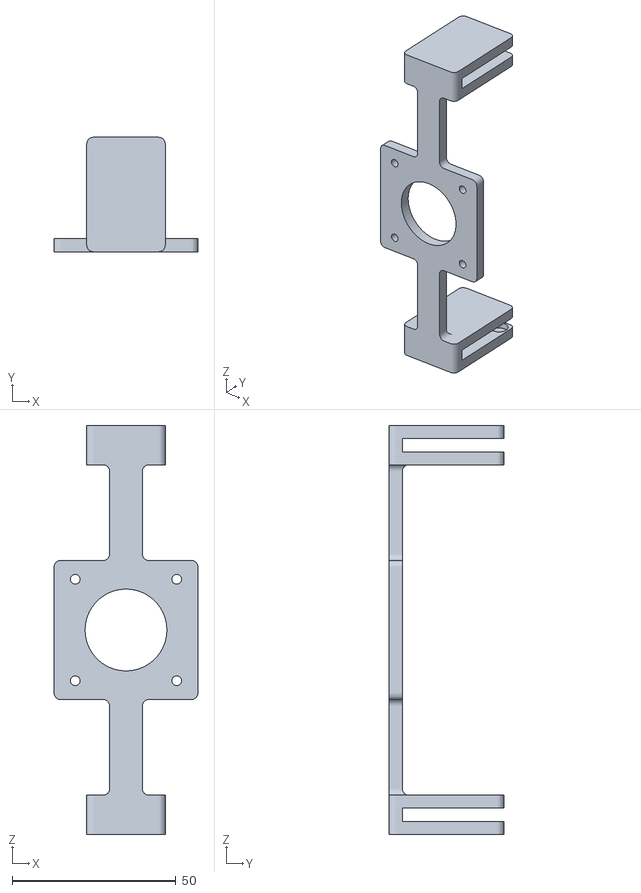
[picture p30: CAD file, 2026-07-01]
Rubic 3D/top brace.stl
44.0 x 35.0 x 125.0

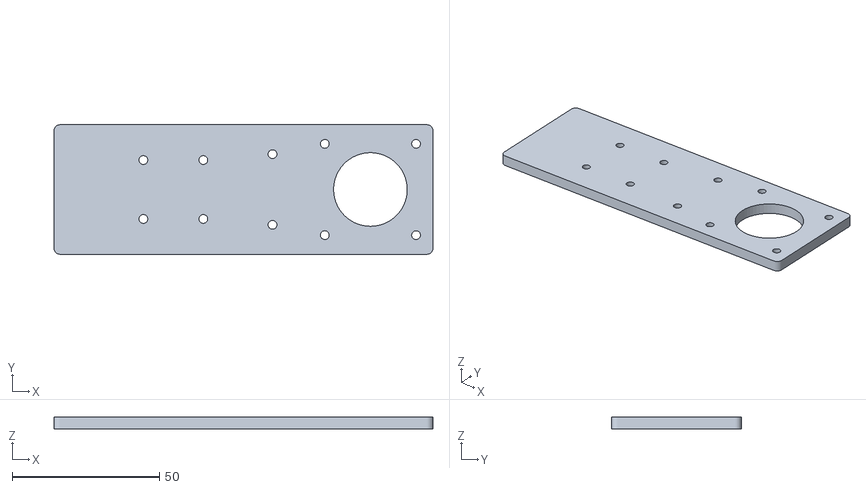
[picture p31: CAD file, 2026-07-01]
Rubic 3D/side plate no magnet final.stl
128.7 x 44.0 x 4.00

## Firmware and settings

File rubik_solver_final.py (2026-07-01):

import cv2
import numpy as np
import kociemba
import time
import threading
import random

try:
    import RPi.GPIO as GPIO
    GPIO_AVAILABLE = True
except ImportError:
    print("[WARNING] RPi.GPIO not found. Motors will not spin.")
    GPIO_AVAILABLE = False

# ══════════════════════════════════════════
# 1. MOTOR CONFIG
# ══════════════════════════════════════════

MOTOR_PINS = {
    'U': {'step': 2,  'dir': 3},
    'D': {'step': 4,  'dir': 14},
    'F': {'step': 15, 'dir': 18},
    'B': {'step': 17, 'dir': 27},
    'L': {'step': 22, 'dir': 23},
    'R': {'step': 24, 'dir': 25},
}
STEPS_PER_90 = 50
STEP_DELAY   = 0.003

def setup_motors():
    if not GPIO_AVAILABLE:
        return
    GPIO.setmode(GPIO.BCM)
    GPIO.setwarnings(False)
    for pins in MOTOR_PINS.values():
        GPIO.setup(pins['step'], GPIO.OUT)
        GPIO.setup(pins['dir'],  GPIO.OUT)
    print("[MOTORS] Initialized.")

def rotate_motor(face, move_type):
    print(f"  -> [{face}] {move_type}")
    if not GPIO_AVAILABLE:
        time.sleep(0.4)
        return
    pins     = MOTOR_PINS[face]
    step_pin = pins['step']
    dir_pin  = pins['dir']

    # D motoru fiziksel olarak ters bağlı, yönü tersle
    REVERSED = {'D'}

    if face in REVERSED:
        cw_signal  = GPIO.LOW
        ccw_signal = GPIO.HIGH
    else:
        cw_signal  = GPIO.HIGH
        ccw_signal = GPIO.LOW

    if   move_type == "CW":  GPIO.output(dir_pin, cw_signal);  steps = STEPS_PER_90
    elif move_type == "CCW": GPIO.output(dir_pin, ccw_signal); steps = STEPS_PER_90
    elif move_type == "180": GPIO.output(dir_pin, cw_signal);  steps = STEPS_PER_90 * 2
    else: return
    for _ in range(steps):
        GPIO.output(step_pin, GPIO.HIGH); time.sleep(STEP_DELAY)
        GPIO.output(step_pin, GPIO.LOW);  time.sleep(STEP_DELAY)
    time.sleep(0.08)

# ══════════════════════════════════════════
# 2. COLOUR & FACE DEFINITIONS
# ══════════════════════════════════════════

FACE_CENTER = {'F':'GREEN','R':'RED','B':'BLUE','L':'ORANGE','U':'WHITE','D':'YELLOW'}

COLOR_BGR = {
    'WHITE':   (255, 255, 255),
    'RED':     (30,  30,  210),
    'GREEN':   (30,  170, 30 ),
    'YELLOW':  (20,  220, 220),
    'ORANGE':  (20,  120, 255),
    'BLUE':    (200, 70,  20 ),
    'EMPTY':   (70,  70,  70 ),
    'UNKNOWN': (130, 0,   130),
}

COLOR_LETTER = {
    'WHITE':'U','RED':'R','GREEN':'F',
    'YELLOW':'D','ORANGE':'L','BLUE':'B',
    'EMPTY':'?','UNKNOWN':'?',
}

# All selectable colors for the manual color picker (popup)
ALL_COLORS = ['WHITE', 'RED', 'GREEN', 'YELLOW', 'ORANGE', 'BLUE']

SCAN_ORDER = ['F','R','B','L','U','D']

INSTRUCTIONS = {
    'F': "1/6  Show GREEN face  (white sticker on top)  ->  press F",
    'R': "2/6  Rotate LEFT  ->  Show RED face  ->  press R",
    'B': "3/6  Rotate LEFT  ->  Show BLUE face  ->  press B",
    'L': "4/6  Rotate LEFT  ->  Show ORANGE face  ->  press L",
    'U': "5/6  Rotate LEFT then DOWN  ->  Show WHITE face  ->  press U",
    'D': "6/6  Tilt DOWN twice  ->  Show YELLOW face  ->  press D",
}

# Face button definitions: (key, label, color_bgr, center_color_name)
FACE_BUTTONS = [
    ('F', 'GREEN',  (30,  160, 30 ), 'GREEN' ),
    ('R', 'RED',    (30,  30,  200), 'RED'   ),
    ('B', 'BLUE',   (180, 60,  20 ), 'BLUE'  ),
    ('L', 'ORANGE', (20,  110, 240), 'ORANGE'),
    ('U', 'WHITE',  (185, 185, 185), 'WHITE' ),
    ('D', 'YELLOW', (20,  200, 205), 'YELLOW'),
]

# ══════════════════════════════════════════
# 3. COLOUR DETECTION
# ══════════════════════════════════════════

def color_guess(h, s, v):
    if s < 90:
        return "WHITE"

    if h < 8 or h >= 160:    return "RED"
    if 8  <= h < 25:         return "ORANGE"
    if 25 <= h < 40:         return "YELLOW"
    if 40 <= h < 55:
        if v > 150:          return "YELLOW"
        else:                return "GREEN"
    if 55 <= h < 90:         return "GREEN"
    if 90 <= h < 140:        return "BLUE"

    return "RED"  # v < 60 dark pixels → kırmızı yüz

# ══════════════════════════════════════════
# 4. CUBE STATE SIMULATOR
# ══════════════════════════════════════════
#
# We need to keep cube_state in sync with the motors when we randomly mix
# the cube — otherwise after mixing, the on-screen map would still show the
# scanned (solved) state, and pressing SOLVE would do nothing useful.
#
# Each face stores 9 stickers in row-major order (indices 0..8):
#   0 1 2
#   3 4 5
#   6 7 8
#
# Rotating a face clockwise (as seen looking AT that face from outside)
# permutes its own 9 stickers AND cycles 4 strips of 3 stickers on the
# 4 adjacent faces.

def _rotate_face_cw(face_list):
    """Rotate a 9-sticker face 90° clockwise (in place)."""
    f = face_list
    # corners cycle
    f[0], f[2], f[8], f[6] = f[6], f[0], f[2], f[8]
    # edges cycle
    f[1], f[5], f[7], f[3] = f[3], f[1], f[5], f[7]

def _rotate_face_ccw(face_list):
    """Rotate a 9-sticker face 90° counter-clockwise (in place)."""
    f = face_list
    f[0], f[6], f[8], f[2] = f[2], f[0], f[6], f[8]
    f[1], f[3], f[7], f[5] = f[5], f[1], f[3], f[7]

# Adjacent-strip definitions for each face turn (CW).
# For each face, list 4 (adjacent_face, [indices]) tuples in the order the
# stickers cycle.  When face X turns CW, the stickers travel:
#   ADJ[0] -> ADJ[1] -> ADJ[2] -> ADJ[3] -> ADJ[0]
#
# Orientation convention used here matches the standard cube net:
#       U
#   L   F   R   B
#       D
# F (front) seen face-on; L on its left, R on its right, U above, D below.
# When we look AT a face, "CW" means the stickers visibly rotate clockwise.

ADJ = {
    'U': [
        ('B', [2, 1, 0]),
        ('R', [2, 1, 0]),
        ('F', [2, 1, 0]),
        ('L', [2, 1, 0]),
    ],
    'D': [
        ('F', [6, 7, 8]),
        ('R', [6, 7, 8]),
        ('B', [6, 7, 8]),
        ('L', [6, 7, 8]),
    ],
    'F': [
        ('U', [6, 7, 8]),
        ('R', [0, 3, 6]),
        ('D', [2, 1, 0]),
        ('L', [8, 5, 2]),
    ],
    'B': [
        ('U', [2, 1, 0]),
        ('L', [0, 3, 6]),
        ('D', [6, 7, 8]),
        ('R', [8, 5, 2]),
    ],
    'L': [
        ('U', [0, 3, 6]),
        ('F', [0, 3, 6]),
        ('D', [0, 3, 6]),
        ('B', [8, 5, 2]),
    ],
    'R': [
        ('U', [8, 5, 2]),
        ('B', [0, 3, 6]),
        ('D', [8, 5, 2]),
        ('F', [8, 5, 2]),
    ],
}

def apply_move(state, face, move_type):
    """
    Apply a single move to the cube state dict (in place).
    state: dict {face_letter -> list of 9 color names}
    face : 'U','D','F','B','L','R'
    move_type: 'CW', 'CCW', or '180'
    """
    if move_type == '180':
        apply_move(state, face, 'CW')
        apply_move(state, face, 'CW')
        return

    # 1) rotate the face's own stickers
    if move_type == 'CW':
        _rotate_face_cw(state[face])
    else:
        _rotate_face_ccw(state[face])

    # 2) cycle the 4 adjacent strips
    chain = ADJ[face]
    # Snapshot strip values  (each strip is a list of 3 sticker color names)
    strips = []
    for adj_face, idxs in chain:
        strips.append([state[adj_face][i] for i in idxs])

    if move_type == 'CW':
        # rotate strips forward: 0->1, 1->2, 2->3, 3->0
        new_strips = [strips[-1]] + strips[:-1]
    else:  # CCW
        # rotate strips backward
        new_strips = strips[1:] + [strips[0]]

    for (adj_face, idxs), new_vals in zip(chain, new_strips):
        for k, i in enumerate(idxs):
            state[adj_face][i] = new_vals[k]

# ══════════════════════════════════════════
# 5. SOLVER & MIXER THREADS
# ══════════════════════════════════════════

solve_state = {
    'running': False, 'solution': '', 'current_move': '',
    'move_index': 0,  'total_moves': 0, 'error': '', 'done': False,
    'mode': 'solve',   # 'solve' or 'mix'
    'mixed_hold_until': 0.0,   # timestamp until which "CUBE MIXED" stays on screen
}

def solver_thread_fn(snap):
    solve_state.update({'running':True,'error':'','solution':'',
                        'current_move':'Calculating...','move_index':0,
                        'total_moves':0,'done':False,'mode':'solve',
                        'mixed_hold_until':0.0})
    try:
        s = ''
        for face in ['U','R','F','D','L','B']:
            for idx, c in enumerate(snap[face]):
                s += COLOR_LETTER[FACE_CENTER[face]] if idx == 4 else COLOR_LETTER.get(c,'?')
        if '?' in s:
            raise ValueError("Unrecognised color. Check lighting and retry.")
        print(f"[SOLVER] {s}")
        solution = kociemba.solve(s)
        print(f"[SOLVER] Solution: {solution}")
        moves = solution.split()
        solve_state['solution']    = solution
        solve_state['total_moves'] = len(moves)
        for i, move in enumerate(moves):
            face  = move[0]
            mtype = "CW" if len(move)==1 else "CCW" if move[1]=="'" else "180"
            solve_state['move_index']   = i + 1
            solve_state['current_move'] = move
            rotate_motor(face, mtype)
        solve_state['current_move'] = 'Done!'
        solve_state['done']         = True
    except Exception as e:
        solve_state['error']        = str(e)
        solve_state['current_move'] = 'Error'
    solve_state['running'] = False


def mixer_thread_fn(state_ref, n_moves=20):
    """
    Generate a random scramble, drive the motors AND update the cube_state
    dict so the on-screen map reflects the new (mixed) state.

    state_ref: the shared cube_state dict (mutated in place).
    """
    solve_state.update({'running':True,'error':'','solution':'',
                        'current_move':'Mixing...','move_index':0,
                        'total_moves':n_moves,'done':False,'mode':'mix',
                        'mixed_hold_until':0.0})
    try:
        faces = ['U','D','F','B','L','R']
        types = ['CW','CCW','180']
        type_labels = {'CW':'', 'CCW':"'", '180':'2'}

        scramble = []
        last_face = None
        for _ in range(n_moves):
            # avoid two moves in a row on the same face (looks silly + redundant)
            choices = [f for f in faces if f != last_face]
            f = random.choice(choices)
            t = random.choice(types)
            scramble.append((f, t))
            last_face = f

        scramble_str = ' '.join(f + type_labels[t] for f, t in scramble)
        solve_state['solution'] = scramble_str
        print(f"[MIXER] Scramble: {scramble_str}")

        for i, (f, t) in enumerate(scramble):
            solve_state['move_index']   = i + 1
            solve_state['current_move'] = f + type_labels[t]
            # update on-screen state BEFORE driving the motor so the map stays
            # in sync even if the user is watching
            apply_move(state_ref, f, t)
            rotate_motor(f, t)

        solve_state['current_move'] = 'Mixed!'
        solve_state['done']         = True
        # hold the "CUBE MIXED" message for 5 seconds before the overlay closes
        solve_state['mixed_hold_until'] = time.time() + 5.0
    except Exception as e:
        solve_state['error']        = str(e)
        solve_state['current_move'] = 'Error'
    solve_state['running'] = False

# ══════════════════════════════════════════
# 6. LAYOUT CONSTANTS  (computed at startup)
# ══════════════════════════════════════════

CAM_W, CAM_H = 640, 480

SCREEN_W = 800
SCREEN_H = 480

layout = {}

def build_layout(sw, sh):
    """
    Divide the screen into:
      - Top bar:  full width, fixed height
      - Left:     camera panel
      - Right:    button panel
        - Face buttons (compacted, 2×3)
        - Action buttons: SOLVE / RANDOM MIX / RESET ALL
        - Cube Net Map (live, fills remaining space)
    """
    top_h     = max(40, int(sh * 0.08))
    content_h = sh - top_h

    cam_panel_w = CAM_W
    cam_panel_h = content_h
    cam_panel_x = 0
    cam_panel_y = top_h

    right_x = cam_panel_w
    right_w  = sw - cam_panel_w
    right_y  = top_h
    right_h  = content_h

    # Face buttons: compacted to ~50% of right height
    pad      = max(8, int(right_w * 0.04))
    btn_gap  = max(5, int(right_w * 0.025))
    n_col, n_row = 2, 3

    grid_w   = right_w - 2 * pad
    grid_h   = int(right_h * 0.36)   # compacted further to give net map more room
    btn_w    = (grid_w - (n_col-1)*btn_gap) // n_col
    btn_h    = (grid_h - (n_row-1)*btn_gap) // n_row

    grid_x   = right_x + pad
    grid_y   = right_y + pad

    # Action buttons row: SOLVE | RANDOM MIX | RESET ALL
    action_y   = grid_y + grid_h + pad
    action_h   = max(36, int(right_h * 0.09))
    action_gap = btn_gap
    total_aw   = grid_w
    solve_w    = int(total_aw * 0.38)
    mix_w      = int(total_aw * 0.34)
    reseta_w   = total_aw - solve_w - mix_w - 2*action_gap
    solve_x    = grid_x
    mix_x      = grid_x + solve_w + action_gap
    reseta_x   = mix_x + mix_w + action_gap

    # Cube net map area: fills remaining space below action buttons
    net_y = action_y + action_h + pad
    net_h = right_h - (net_y - right_y) - pad
    net_x = right_x
    net_w = right_w

    status_y = action_y + action_h + 6

    return {
        'top_h':      top_h,
        'cam_x':      cam_panel_x,
        'cam_y':      cam_panel_y,
        'cam_w':      cam_panel_w,
        'cam_h':      cam_panel_h,
        'right_x':    right_x,
        'right_y':    right_y,
        'right_w':    right_w,
        'right_h':    right_h,
        'grid_x':     grid_x,
        'grid_y':     grid_y,
        'btn_w':      btn_w,
        'btn_h':      btn_h,
        'btn_gap':    btn_gap,
        'n_col':      n_col,
        'n_row':      n_row,
        'solve_x':    solve_x,
        'solve_w':    solve_w,
        'mix_x':      mix_x,
        'mix_w':      mix_w,
        'reseta_x':   reseta_x,
        'reseta_w':   reseta_w,
        'action_y':   action_y,
        'action_h':   action_h,
        'status_y':   status_y,
        'net_x':      net_x,
        'net_y':      net_y,
        'net_w':      net_w,
        'net_h':      net_h,
        'pad':        pad,
    }

# ══════════════════════════════════════════
# 7. DRAW FUNCTIONS
# ══════════════════════════════════════════

def draw_camera_panel(canvas, frame_cam, L):
    cx = L['cam_x']
    cy = L['cam_y']
    ch = L['cam_h']
    cw = L['cam_w']

    cam_h, cam_w = frame_cam.shape[:2]
    scale  = min(cw / cam_w, ch / cam_h)
    dw     = int(cam_w * scale)
    dh     = int(cam_h * scale)
    scaled = cv2.resize(frame_cam, (dw, dh))
    ox     = cx + (cw - dw) // 2
    oy     = cy + (ch - dh) // 2
    canvas[oy:oy+dh, ox:ox+dw] = scaled

    cv2.rectangle(canvas, (cx, cy), (cx+cw-1, cy+ch-1), (60,60,60), 1)
    return ox, oy, dw, dh


def draw_cube_grid(canvas, frame_cam, ox, oy, dw, dh,
                   face, temp_colors, saved_colors, manual_select_mode=False):
    """
    Draw the 3×3 colour grid centred on the camera image.
    Returns list of (x1,y1,x2,y2) for each cell (for manual click detection).
    """
    cx = ox + dw // 2
    cy = oy + dh // 2

    box  = max(32, int(dh * 0.08))
    step = max(46, int(dh * 0.12))

    center_name = FACE_CENTER.get(face, 'UNKNOWN')
    use_saved   = len(saved_colors) == 9
    colors      = saved_colors if use_saved else temp_colors
    border_clr  = (60, 255, 60) if use_saved else (220, 220, 220)
    if manual_select_mode:
        border_clr = (0, 200, 255)   # cyan highlight when in manual mode
    fs = max(0.45, box / 50)

    cell_rects = []
    for row, dy in enumerate((-1, 0, 1)):
        for col, dx in enumerate((-1, 0, 1)):
            idx  = row * 3 + col
            rx   = cx + dx * step - box // 2
            ry   = cy + dy * step - box // 2
            rx2, ry2 = rx + box, ry + box
            cell_rects.append((rx, ry, rx2, ry2))

            if idx == 4:
                fill = COLOR_BGR[center_name]
                cv2.rectangle(canvas, (rx,ry), (rx2,ry2), fill, -1)
                cv2.rectangle(canvas, (rx,ry), (rx2,ry2), (255,255,255), 2)
                ltr = center_name[0]
                tc  = (0,0,0)
            else:
                cname = colors[idx] if idx < len(colors) else 'UNKNOWN'
                fill  = COLOR_BGR.get(cname, COLOR_BGR['UNKNOWN'])
                cv2.rectangle(canvas, (rx,ry), (rx2,ry2), fill, -1)
                cv2.rectangle(canvas, (rx,ry), (rx2,ry2), border_clr, 2)
                ltr = cname[0] if cname not in ('EMPTY','UNKNOWN') else '?'
                tc  = (0,0,0) if cname == 'WHITE' else (255,255,255)

            tx = rx + max(6, box//5)
            ty = ry + max(20, int(box*0.68))
            cv2.putText(canvas, ltr, (tx,ty),
                        cv2.FONT_HERSHEY_SIMPLEX, fs, tc, 2)

    # Manual mode hint
    if manual_select_mode:
        hint = "MANUAL MODE - click a cell"
        cv2.putText(canvas, hint, (ox + 4, oy + dh - 8),
                    cv2.FONT_HERSHEY_SIMPLEX, 0.45, (0, 200, 255), 1)

    return cell_rects


def draw_top_bar(canvas, sw, L, next_face, manual_mode=False, all_done=False):
    h = L['top_h']
    cv2.rectangle(canvas, (0,0), (sw, h), (18,18,18), -1)
    if manual_mode:
        txt = "MANUAL MODE  |  Click a cell on cam or cube map  |  M = exit"
        col = (0, 200, 255)
    elif next_face:
        txt = INSTRUCTIONS.get(next_face, '')
        col = (60, 255, 130)
    elif all_done:
        txt = "ALL FACES SCANNED  -  Press SOLVE  (or RANDOM MIX with a solved cube)"
        col = (60, 255, 255)
    else:
        txt = "RANDOM MIX = scramble a solved cube  |  Scan all 6 faces to SOLVE"
        col = (200, 200, 200)
    # Fixed readable font size, scale down only if text overflows
    fs = 0.52
    (tw, _), _ = cv2.getTextSize(txt, cv2.FONT_HERSHEY_SIMPLEX, fs, 2)
    if tw > sw - 24:
        fs = fs * (sw - 24) / tw
    cv2.putText(canvas, txt, (12, h - 10),
                cv2.FONT_HERSHEY_SIMPLEX, fs, col, 2)


# ── Cube Net Map ──────────────────────────────────────────────────────────────
#
# Standard cube net layout (cross):
#
#           [ U ]
#  [ L ][ F ][ R ][ B ]
#           [ D ]
#
# We map each face to a grid position (col, row) in this cross.
NET_LAYOUT = {
    'U': (1, 0),
    'L': (0, 1),
    'F': (1, 1),
    'R': (2, 1),
    'B': (3, 1),
    'D': (1, 2),
}
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
